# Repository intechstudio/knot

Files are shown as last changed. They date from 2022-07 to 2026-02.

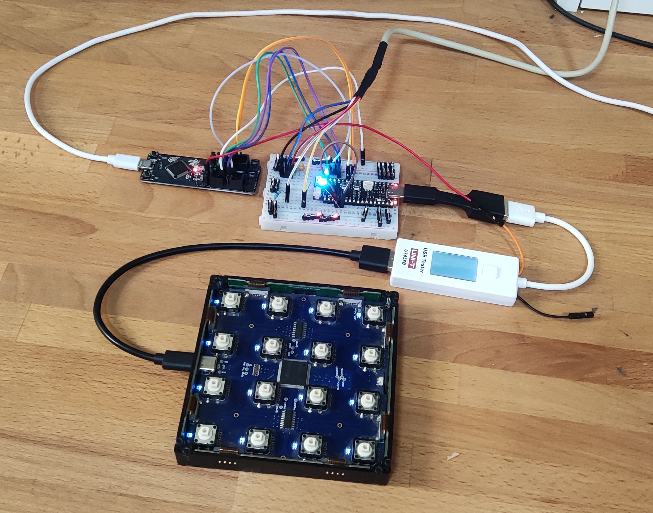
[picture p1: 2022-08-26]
Documentation/prototype.jpg

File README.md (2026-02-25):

## KNOT - USB MIDI Host

Knot is the bridge between old-school MIDI gear like synthesizers, groove boxes, guitar pedals and neat USB MIDI devices. Leave out the computer from the equation and control instruments seamlessly with Grid - or any other - USB controller.

knot, the standalone usb midi host

You can find more info on the [website](https://intech.studio/shop/knot) or in the [Knot - Starter's Guide](https://docs.intech.studio/guides/knot/knot-start).

## Electrical components

| Component | Part number | Preview | Links |
|---|---|---|---|
| KNOT board | PCBA-KNOT |   | [[Schematic]](https://github.com/intechstudio/knot/releases/download/nightly-electrical/PCBA-KNOT_Schematic.pdf) [[STEP]](https://github.com/intechstudio/knot/releases/download/nightly-electrical/PCBA-KNOT-3D.step) [[Gerber]](https://github.com/intechstudio/knot/releases/download/nightly-electrical/PCBA-KNOT-gerber.zip) [[PCB Top]](https://github.com/intechstudio/knot/releases/download/nightly-electrical/PCBA-KNOT_PCB_Top.pdf) [[PCB Bottom]](https://github.com/intechstudio/knot/releases/download/nightly-electrical/PCBA-KNOT_PCB_Bottom.pdf) [[BOM]](https://github.com/intechstudio/knot/releases/download/nightly-electrical/PCBA-KNOT-bom.csv) [[Interactive BOM]](https://github.com/intechstudio/knot/releases/download/nightly-electrical/PCBA-KNOT-ibom.html) |

## Mechanical components

| Component | Part number | Type | Preview | Links |
|---|---|---|---|---|
| Aluminum housing | KNOT-HOUSING | Fabricated |  | [[step]](https://github.com/intechstudio/knot/releases/download/nightly-mechanical/KNOT-HOUSING.step) [[stl]](https://github.com/intechstudio/knot/releases/download/nightly-mechanical/KNOT-HOUSING.stl) [[pdf]](https://github.com/intechstudio/knot/releases/download/nightly-mechanical/KNOT-HOUSING_Drawing.pdf) [[engraving]](https://github.com/intechstudio/knot/releases/download/nightly-mechanical/KNOT-HOUSING_Engraving.pdf) |
| Aluminum front panel | KNOT-FRONT | Fabricated |  | [[step]](https://github.com/intechstudio/knot/releases/download/nightly-mechanical/KNOT-FRONT.step) [[stl]](https://github.com/intechstudio/knot/releases/download/nightly-mechanical/KNOT-FRONT.stl) [[pdf]](https://github.com/intechstudio/knot/releases/download/nightly-mechanical/KNOT-FRONT_Drawing.pdf) |
| Aluminum back panel | KNOT-BACK | Fabricated |  | [[step]](https://github.com/intechstudio/knot/releases/download/nightly-mechanical/KNOT-BACK.step) [[stl]](https://github.com/intechstudio/knot/releases/download/nightly-mechanical/KNOT-BACK.stl) [[pdf]](https://github.com/intechstudio/knot/releases/download/nightly-mechanical/KNOT-BACK_Drawing.pdf) |

### Nightly Firmware version

The nightly firmware is an early release version of the stable release. As it is an early version, some issues could still persist. In the case of issues, please denote the usage of a nightly firmware in the issue report.

[Nightly Release](https://github.com/intechstudio/knot/releases/tag/nightly)

### Updating the firmware

- Hold the mode button while plugging the device using the USB-C port of the Knot.
- The device is identified as a USB mass storage named KNOT-S3 (3 green LEDs).
- The file "INFO_UF2.txt" only contains information for the bootloader version, not the firmware itself.
- You can check the current firmware version, opening the file "CURRENT.UF2" with a text or hexadecimal application.
- The first lines will contain the firmware date text. (e.g "May 29 2024" for the firmware "v1.0.5").
- Download the file "knot_release.zip" from the latest release [Stable Release](https://github.com/intechstudio/knot/releases) and extract it.
- Do not rename the ".uf2" file and copy it to the KNOT-S3 mass storage.
- The device will update and reboot alone.
- 3 blinking white LEDs means that the update is finished and that the device is waiting to a USB MIDI device.

### Knot features

- Standalone USB MIDI Host, works with Grid and any MIDI class compliant USB controller
- TRS MIDI input port
- TRS MIDI output port
- USB-C port for powering, updating the device
- DC in port for powering (6V or 15V with automatic polarity detection)
- Hardware A/B switch for changing the TRS wiring mode
- Mode button for updating the firmware
- 3 indicator LEDs, which will be utilized for various feedback

### USB MIDI Device compatibility with Knot as a host

*If you own a device you couldn't find in the list below, help us out by submitting a test of your own to support@intech.studio!*

| Manufacturer | Device name | Compatibility with Knot | Tester | Note |
| ---- | ---- | ---- | ---- | --- |
| Intech Studio  | Grid | Tested - OK | Intech | |
| Alesis  | Qmini  |  Tested - Not working | Community | |
| AKAI  | MPK Mini MK2  |  Tested - OK | Community | |
| AKAI  | MPK Mini Plus  |  Tested - OK | Community | |
| Arturia  | Beatstep (non-Pro)  |  Tested - OK | Community | |
| Arturia  | Keystep  |  Tested - OK | Community | |
| Arturia  | MiniLab MK2 |  Tested - OK | Community | |
| DoReMIDI  | USB-C MIDI adapter  |  Tested - OK | Community | |
| Elektron  | Digitakt |  Tested - Not working | Community | |
| Korg  | Electribe ES2  |  Tested - OK | Intech | |
| Korg  | Microkey Air 37  |  Tested - OK | Community | |
| Korg  | Nanokey 2  |  Tested - OK | Community | |
| Korg  | Nanopad 2  |  Tested - Not working | Community | |
| Livid Instruments  | DS-1  |  Tested - OK | Community | |
| Midi Fighter  | Midi Fighter Twister  |  Tested - OK | Community | |
| M-AUDIO  | MIDISPORT UNO | Tested - OK | Intech | |
| M-AUDIO | Keystation MK3 (all key sizes) | Tested - Not working | Intech | |
| Novation  | Circuit | Tested - OK | Community | |
| Novation | Launch Control XL2  | Tested - OK | Community | |
| Novation | Launchpad MK3 Mini  | Tested - OK | Intech | |
| Novation  | Launchpad MK2 | Tested - OK | Intech | |
| Novation  | Launchkey 25 | Tested - Only Power | Intech | |
| Roland  | MC-101 | Tested - OK | Community | |
| Sonicware  | ELZ_1  |  Tested - OK | Community | |
| Teenage Engineering  | EP-133 |  Tested - OK | Community | *Knot supplies ample power to the device* |
| Teenage Engineering  | OP-1  |  Tested - No MIDI | Community | |
| Teenage Engineering  | OP-1 field |  Tested - No MIDI | Community | |
| Teenage Engineering  | OP-Z |  Tested - OK | Community | |

### 5-pin DIN/TRS MIDI Device compatibility

*If you own a device you couldn't find in the list below, help us out by submitting a test of your own to support@intech.studio!*

| Manufacturer | Device name | MIDI connector |Compatibility | Tester | Note |
| ---- | ---- | ---- | ---- | ---- | --- |
| 1010music | Blackbox | TRS type-B | Tested - OK |  Community | |
| 1010music | Bluebox | TRS type-B | Tested - OK |  Community | |
| Arturia  | Beatstep (non-Pro) | TS "type-C" |  Tested - !!! | Community | *Needs 3.5mm TS to TRS adapter* |
|Behringer | TD-3-AM | 5-pin DIN | Tested - OK |  Intech | *With adapter* |
|Behringer | U-PHORIA UMC404HD | 5-pin DIN | Tested - OK | Intech | *With adapter* |
| Dreadbox  | Nymphes  | TRS type-B  | Tested - OK | Community | |
| Elektron  | Digitakt | 5-pin DIN | Tested - OK | Community | *With adapter* |
| Korg  | Electribe ES2  | TRS type-B  | Tested - OK | Intech | |
| Korg | Volca Series (Tested on Volca FM)  |  5-pin DIN | Tested - OK | Intech | *With adapter* |
| Mutable Instruments | Yarns | 5-pin DIN | Tested - OK | Intech | *With adapter* |
| Polyend  | Tracker  | TRS type-B | Tested - OK | Intech | |
| Teenage Engineering  | EP-133 | TRS type-A | Tested - OK | Community |  |
| Teenage Engineering  | OP-Z | TRS type-A | Tested - OK | Community | *With Line Module* |
| Woovebox  | Woovebox | TRS type-A | Tested - OK | Community | |

<!---
### Community contributors

A big thank you to our community contributors for testing these devices:
- Michal
- Tibi

|    Dirtywave  | M8 Tracker  | TRS type-A | Untested | - |
|   Audiothingies   | Micromonsta 2  | TRS type-A | Untested | - |
|    Bastl Instruments  | Softpop SP2  | 5-pin DIN | Untested | - |
|    Elektron  | Octatrack  | 5-pin DIN | Untested | - |
|    Elektron  | Syntax  | 5-pin DIN | Untested | - |
|    Elektron  | Digitakt  | 5-pin DIN | Untested | - |
|    Elektron  | Digitone  | 5-pin DIN | Untested | - |
|    Elektron  | Analog Rytm  | 5-pin DIN | Untested | - |
|    Elektron  | Analog Four  | 5-pin DIN | Untested | - |
|    Elektron  | Analog Keys  | 5-pin DIN | Untested | - |
|    Elektron  | Model:Samples  | TRS type-A | Untested | - |
|    Elektron  | Model:Cycles  | TRS type-A | Untested | - |
|    Arturia  | Microfreak  | TRS type-A  | Untested | - |
--->

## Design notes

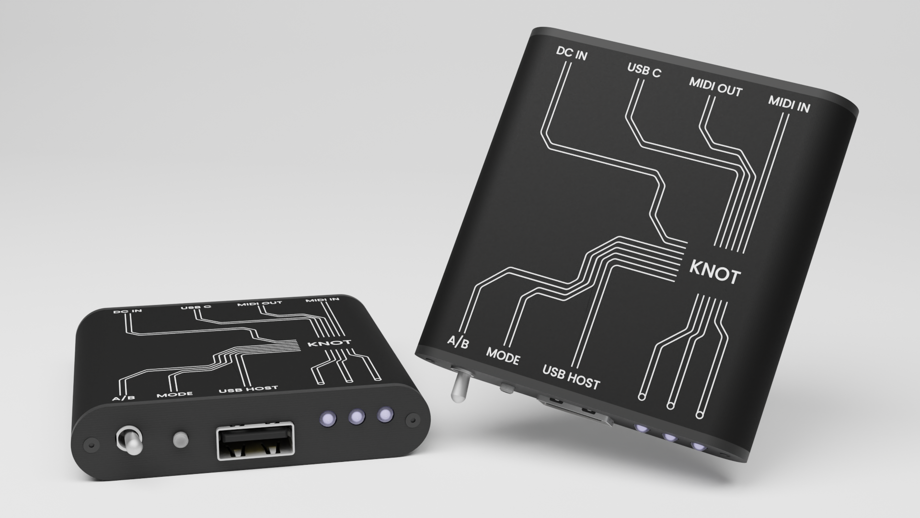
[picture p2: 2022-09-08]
Documentation/knot.png

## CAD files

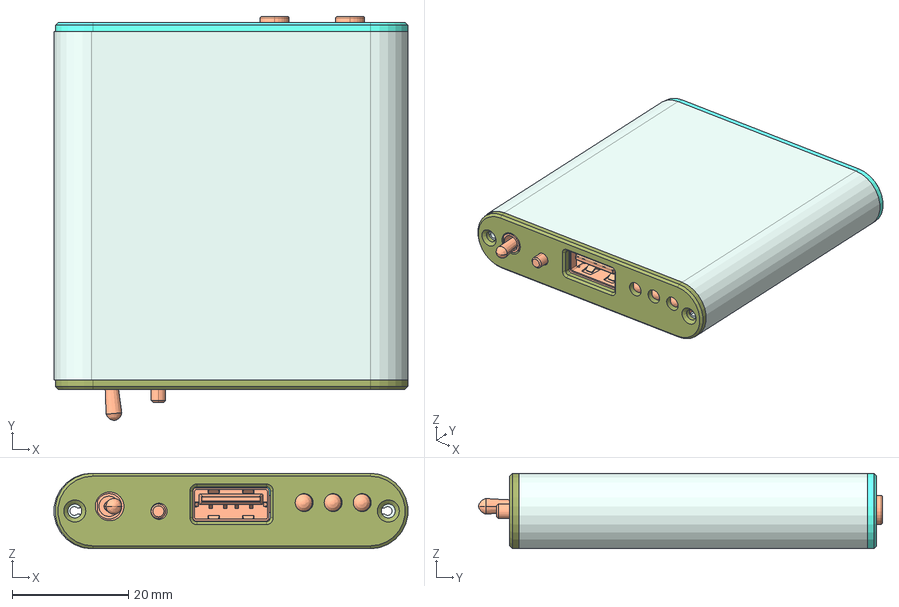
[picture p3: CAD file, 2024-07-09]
Mechanical/Design/KNOT-ASSEMBLY/KNOT-ASSEMBLY.FCStd
60.9 x 69.6 x 13.0 mm
KNOT-PCB_001
KNOT-HOUSING_001
KNOT-FRONT_001
KNOT-BACK_001

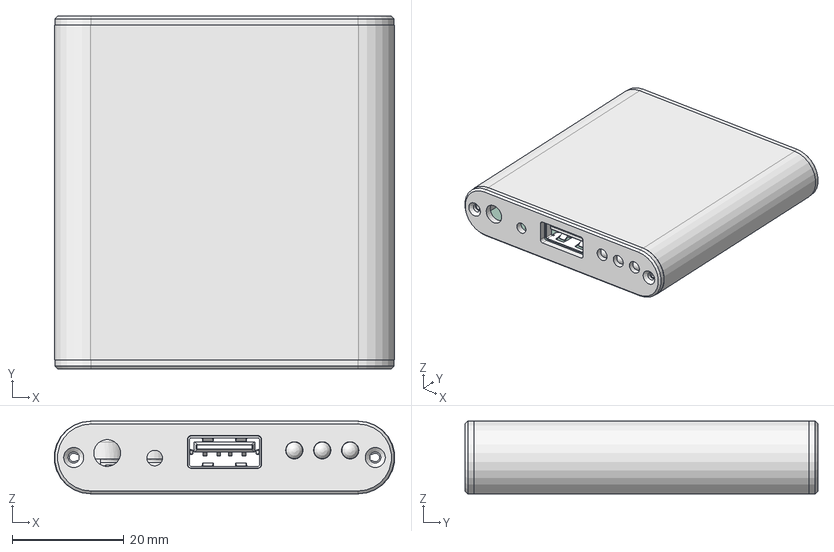
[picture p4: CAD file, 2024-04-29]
Mechanical/MIDI_Host_assembly.FCStd
60.9 x 63.2 x 13.0 mm
Alu
Front
Back
PCBA-KNOT PCB

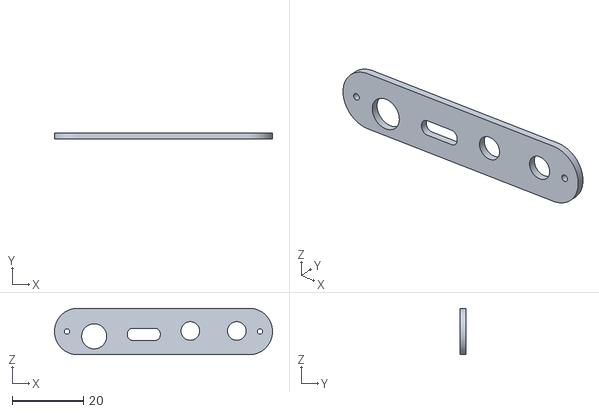
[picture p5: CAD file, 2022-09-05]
Render/render/MIDI_Host_assembly-Back.stl
61.0 x 1.60 x 13.0

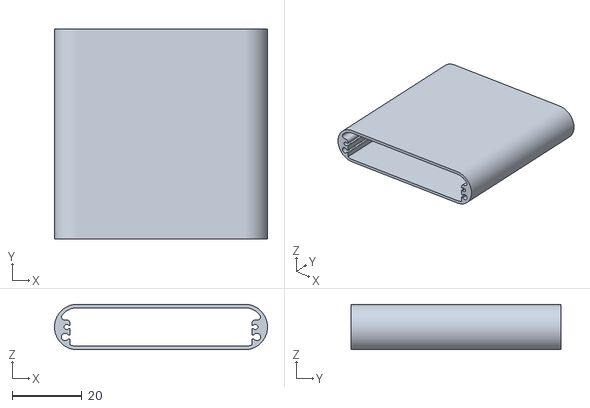
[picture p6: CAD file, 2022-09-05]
Render/render/MIDI_Host_assembly-Alu.stl
61.0 x 60.0 x 13.0

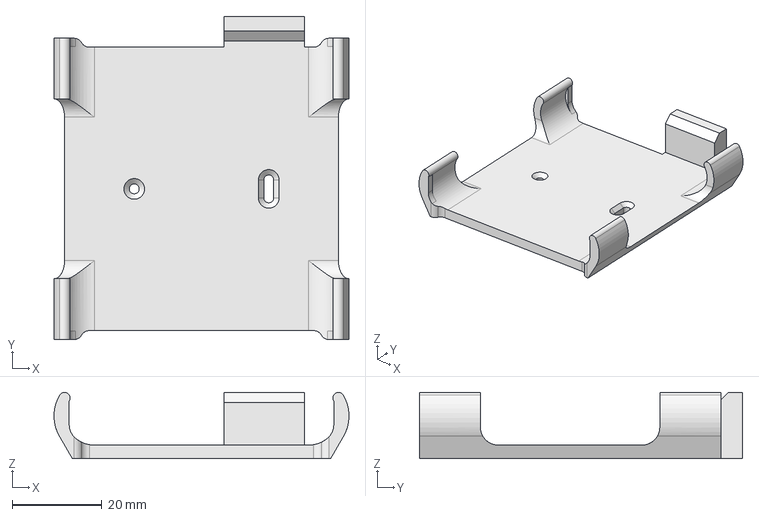
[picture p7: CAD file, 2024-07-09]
Mechanical/Design/KNOT-HOLDER/KNOT-HOLDER.FCStd
65.8 x 72.1 x 14.7 mm

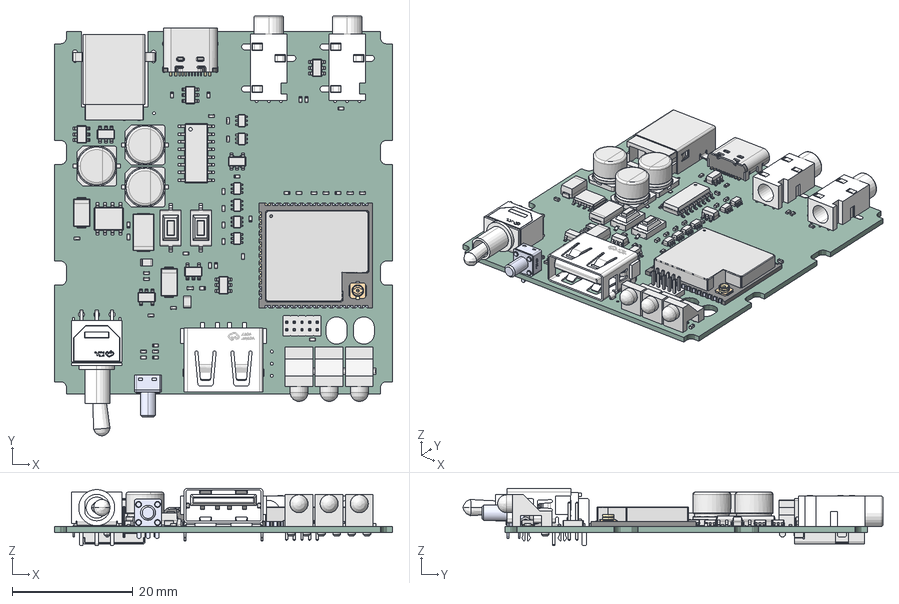
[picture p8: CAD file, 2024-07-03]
Mechanical/Design/KNOT-PCB/KNOT-PCB.FCStd
56.0 x 69.6 x 9.50 mm
R_0402_1005Metric063
SOT_363_SC_70_012
C_0402_1005Metric066
C_0402_1005Metric068
R_0402_1005Metric065
D_SMA006
LEG012
LEG013
LEG014
LEG015
ESP32-S3-WROOM-1U057
ESP32-S3-WROOM-1U058
ESP32-S3-WROOM-1U059
ESP32-S3-WROOM-1U060
ESP32-S3-WROOM-1U061
ESP32-S3-WROOM-1U062
ESP32-S3-WROOM-1U063
ESP32-S3-WROOM-1U064
ESP32-S3-WROOM-1U065
ESP32-S3-WROOM-1U066
ESP32-S3-WROOM-1U067
ESP32-S3-WROOM-1U068
ESP32-S3-WROOM-1U069
ESP32-S3-WROOM-1U070
ESP32-S3-WROOM-1U071
ESP32-S3-WROOM-1U072
ESP32-S3-WROOM-1U073
ESP32-S3-WROOM-1U074
ESP32-S3-WROOM-1U075
ESP32-S3-WROOM-1U076
ESP32-S3-WROOM-1U077
ESP32-S3-WROOM-1U078
ESP32-S3-WROOM-1U079
ESP32-S3-WROOM-1U080
ESP32-S3-WROOM-1U081
ESP32-S3-WROOM-1U082
ESP32-S3-WROOM-1U083
ESP32-S3-WROOM-1U084
ESP32-S3-WROOM-1U085
ESP32-S3-WROOM-1U086
ESP32-S3-WROOM-1U087
ESP32-S3-WROOM-1U088
ESP32-S3-WROOM-1U089
ESP32-S3-WROOM-1U090
ESP32-S3-WROOM-1U091
ESP32-S3-WROOM-1U092
ESP32-S3-WROOM-1U093
ESP32-S3-WROOM-1U094
ESP32-S3-WROOM-1U095
ESP32-S3-WROOM-1U096
ESP32-S3-WROOM-1U097
ESP32-S3-WROOM-1U098
ESP32-S3-WROOM-1U099
ESP32-S3-WROOM-1U100
ESP32-S3-WROOM-1U101
ESP32-S3-WROOM-1U102
ESP32-S3-WROOM-1U103
ESP32-S3-WROOM-1U104
ESP32-S3-WROOM-1U105
ESP32-S3-WROOM-1U106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

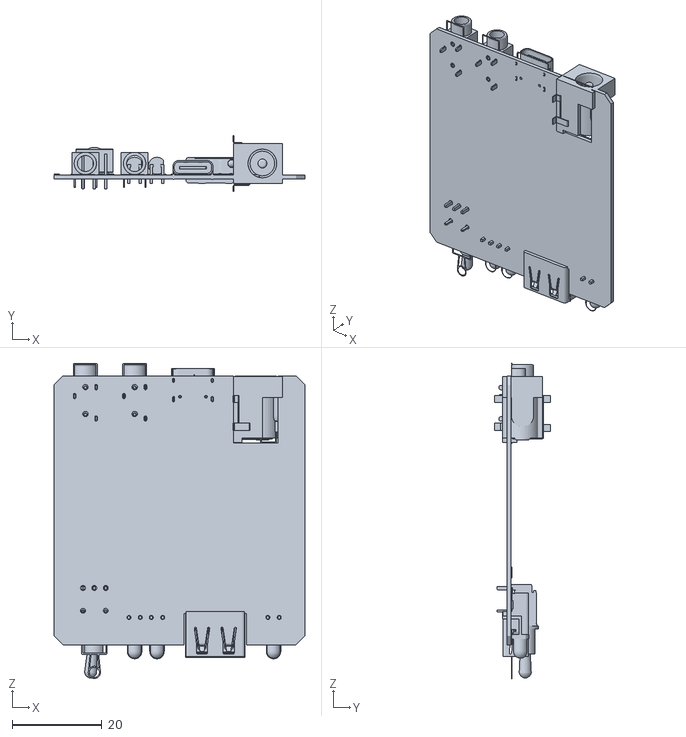
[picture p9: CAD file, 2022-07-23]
Render/untitled.stl
56.0 x 12.5 x 70.3

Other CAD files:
Render/render/MIDI_Host_assembly-Front.stl
Mechanical/Design/KNOT-BACK/KNOT-BACK.FCStd
Mechanical/Design/KNOT-FRONT/KNOT-FRONT.FCStd
Mechanical/Design/KNOT-HOUSING/KNOT-HOUSING.FCStd
Mechanical/Design/KNOT_mfg/KNOT-BACK.step
Mechanical/Design/KNOT_mfg/KNOT-FRONT.step
Mechanical/Design/KNOT_mfg/KNOT-HOUSING.step
Mechanical/Design/archive/mfg/MIDI_Host_assembly-Front2.step
Mechanical/Design/archive/mfg/MIDI_Host_assembly-Front.step
Mechanical/Design/archive/mfg/MIDI_Host_assembly-Alu.step
Mechanical/Design/archive/mfg/MIDI_Host_assembly-Back.step

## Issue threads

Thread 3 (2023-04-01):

Possible to make USB HOST driver "pluggable"?

marchingband, 2023-04-01:
When I unplug a USB device, the application crashes.
```
E (10592) USBH: Device 1 gone
ESP_ERROR_CHECK failed: esp_err_t 0x103 (ESP_ERR_INVALID_STATE) at 0x40378f54
```

PS. I am fan-boy-ing out over here, all your products are fantastic <3

marchingband, 2023-04-01:
I see in the example code:
```
        if (driver_obj.actions == 0) {
            usb_host_client_handle_events(driver_obj.client_hdl, portMAX_DELAY);
        } else {
            ... we handle events
        }
```

but in yours:
```
        usb_host_client_handle_events(driver_obj.client_hdl, 10);
        ... we handle events
```
Perhaps this leaves the driver in an invalid state such that it cannot be deregistered / uninstalled?

marchingband, 2023-04-01:
running the example code from esp-idf, when I unplug a device I get:
```
E (259720) USBH: Device 1 gone
I (259720) CLASS: Deregistering Client
I (259720) DAEMON: No more clients and devices
```
So the daemon task is seeing that the client is gone and can close well, which does not happen in yours, this 3rd log never occurs.

marchingband, 2023-04-01:
I see you replaced `driver_obj->actions &= ~ACTION_GET_STR_DESC;` in the get_string_descriptor with a loop counter.
I wonder if you could help me understand why this is setup the way it is. I would love to help get this running as a pluggable driver.

marchingband, 2023-04-01:
Ok I have fixed it but there are some major changes, l'll outline them here, just let me know if you'd like a PR, or if you want to discuss, or if you don't care that's totally understandable too, I realize that your device works perfectly just crashing and starting from the beginning.
I will leave some code here to help anyone else who may end up here.

`aciton_close_dev()` deletes some info that is needed to close the host, so I don't call that, instead, when the callback receives `ACTION_CLOSE_DEV`, just break
```
            if (driver_obj.actions & ACTION_CLOSE_DEV) {
                // aciton_close_dev(&driver_obj);
                break;
            }
```
 and then here is the closing code which I add at the end of `class_driver_task()`
```
    // Cancel polling of BULK IN and OUT endpoints
    transfer->callback = NULL;
    in_transfer->callback = NULL;

    // Reset the endpoints
    ESP_ERROR_CHECK(usb_host_endpoint_halt(driver_obj.dev_hdl, transfer->bEndpointAddress));
    ESP_ERROR_CHECK(usb_host_endpoint_flush(driver_obj.dev_hdl, transfer->bEndpointAddress));

    ESP_ERROR_CHECK(usb_host_endpoint_halt(driver_obj.dev_hdl, in_transfer->bEndpointAddress));
    ESP_ERROR_CHECK(usb_host_endpoint_flush(driver_obj.dev_hdl, in_transfer->bEndpointAddress));

    ESP_LOGI(TAG, "Free transfers");
    ESP_ERROR_CHECK(usb_host_transfer_free(transfer));

    ESP_LOGI(TAG, "Free in_transfers");
    ESP_ERROR_CHECK(usb_host_transfer_free(in_transfer));

    // Release the host
    ESP_ERROR_CHECK(usb_host_interface_release(driver_obj.client_hdl, driver_obj.dev_hdl, interface_num ));

    // Close the device
    ESP_ERROR_CHECK(usb_host_device_close(driver_obj.client_hdl, driver_obj.dev_hdl));

    ESP_LOGI(TAG, "Deregistering Client");
    ESP_ERROR_CHECK(usb_host_client_deregister(driver_obj.client_hdl));

    //Wait to be deleted
    ESP_LOGI(TAG, "Giving semaphore");
    xSemaphoreGive(signaling_sem);

    ESP_LOGI(TAG, "Suspending self");
    vTaskSuspend(NULL);
```
The only special value in here is `interface_num` which I declare globally
```
uint8_t interface_num = 0;
```
And inside `action_get_config_desc()` I added one line
```
    ESP_LOGI(TAG, "SUKU claim interface %d nice", intf_num);
    ESP_ERROR_CHECK(usb_host_interface_claim(driver_obj->client_hdl, driver_obj->dev_hdl, intf_num, 0));

    // save the intf_num for deregistration
    interface_num = intf_num;

    usb_host_transfer_alloc(4, 0, &transfer);
```
This code closes the host driver, after which we can run everything from scratch, and wait for a new device.
How to best handle this plug/unplug cycle is up for debate, but I have a task that manages the plugging. It starts the tasks, waits on the semaphore, and then deletes the tasks, in a loop.

```
static void usb_h_task(void *arg)
{
    while(1)
    {
        ESP_LOGI(TAG, "creating usb host driver tasks");
        SemaphoreHandle_t signaling_sem = xSemaphoreCreateBinary();

        TaskHandle_t daemon_task_hdl;
        TaskHandle_t class_driver_task_hdl;

        //Create daemon task
        xTaskCreatePinnedToCore(host_lib_daemon_task,
                                "usb_h_daemon",
                                4096,
                                (void *)signaling_sem,
                                DAEMON_TASK_PRIORITY,
                                &daemon_task_hdl,
                                0);

        //Create the class driver task
        xTaskCreatePinnedToCore(class_driver_task,
                                "usb_h_class",
                                4096,
                                (void *)signaling_sem,
                                CLASS_TASK_PRIORITY,
                                &class_driver_task_hdl,
                                0);

        vTaskDelay(10);     //Add a short delay to let the tasks run

        //Wait for the tasks to complete
        xSemaphoreTake(signaling_sem, portMAX_DELAY);

        ESP_LOGI(TAG, "deleteting usb host tasks");
        //Delete the tasks
        vTaskDelete(class_driver_task_hdl);
        vTaskDelete(daemon_task_hdl);
    }

}
```
I imagine there are some memory leaks in here, and maybe some unnecessary steps or easier ways to do things, but, I plugged and unplugged like a crazy person and it seems to work well.
Ok over and out <3

marchingband, 2023-04-01:
The end product:
https://github.com/ultrapalace/mainframe/blob/main/main/usb_h.c
https://github.com/ultrapalace/mainframe/blob/main/main/usb_h_class.c

Closed 2023-04-01.

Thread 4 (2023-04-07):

I can connect to upload the firmware, but how?

giacecco, 2023-04-07:
The page at https://intech.studio/shop/knot describes how to connect with the Knot to upgrade the firmware, but doesn't say what to do next!

I can see that there is a `CURRENT.UF2` file in the Knot, while the latest release at https://github.com/intechstudio/knot/releases includes a `knot_release_2023-02-08-1025.uf2` file. Shall I overwrite the old one? Shall I just upload the new one without renaming? I don't want to risk bricking it.

In the Knot I also see an `INFO_UF2.TXT` file saying:

```
TinyUF2 Bootloader ca0cacd - tinyusb (0.12.0-203-ga4cfd1c69)
Model: Intech Studio Knot
Board-ID: ESP32S3-Knot
Date: Sep  7 2022
```

... so it looks like a firmware update is due!

Closed 2023-07-20.

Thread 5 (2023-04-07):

Voltage for DC-in?

giacecco, 2023-04-07:
At the back of the Knot, it says `6-15V DC`. It looks like it could take anything _between_ 6 and 15, but in reality, it wants exactly 6 or 15. I tried with a 9V I use with my pedal and the Knot did not turn on. Please change the label to `6V or 15V DC`.

I have made a pull requests to update the website accordingly, too.

SukuWc, 2023-07-20:
What polarity is the 9V power supply? Early on knot units the automatic polarity detection was not working correctly, so if the power supply is center negative variant (typically used by guitar pedals) then that could be the problem!

Closed 2024-01-09.

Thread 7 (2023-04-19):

MIDI received on TRS IN causes power cycle on Knot when hosting some devices

narayb, 2023-04-19:
Reproduced on Novation Launchpad MK3 Mini.
No effect when hosting Grid.

SukuWc, 2023-07-20:
Can we confirm that this is still a problem using v1.0.2 firmware on knot

Closed 2024-01-09.

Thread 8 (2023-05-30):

FW Update = Pulsing white LED's

lucasfackler, 2023-05-30:
After dropping the latest release .UF2 onto the disk, Knot reboots and now LED's are white and pulse slowly.
What does this mean? No MIDI either.

SukuWc, 2023-07-20:
That means that knot is waiting for a MIDI controller to be connected! What midi controller are you trying to connect?

narayb, 2023-07-20:
We have solved this issue a while back, you can close it if that's alright with you.

Closed 2024-01-09.

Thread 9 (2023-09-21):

Feature request: let Knot remember the Mode setting

narayb, 2023-09-21:
In certain workflows users would use the Blue Mode with MIDI Through/Merge exclusively, but at the moment this requires setting the Mode after each power cycle.

It would be preferable if Knot could remember the last Mode set until the next boot.

mulkeybe, 2023-11-09:
This would be a very useful feature. I run an external Midi clock into my knot and merge it with Grid controller MIDI data stream. It would be nice if knot would remember the mode so I wouldn’t have to press the utility button every time that I power up my system

narayb, 2023-11-09:
This is a work in progress feature, more news soon!

kkerti, 2024-01-13:
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
Please let me (or users on the discord community channel) know if we have an ETA for this.

SukuWc, 2024-03-18:
Feature implemented, fix coming soon in firmware version v1.0.3

Closed 2024-03-18.

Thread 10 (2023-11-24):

Add instructions for updating firmware

jmickelin, 2023-11-24:
There doesn't seem to be any clear instructions for updating the firmware, either here on Github or on the retail page. The latter has a link called "Firmware update" on https://docs.intech.studio/, but it takes you to a page describing firmware updates only for the Grid controllers.

One _could_ deduce that updating works similarly on the Knot as the instructions under the "Updating the firmware manually" section on the Grid page (holding the mode button while connecting the USB-C port to a computer makes the Knot present itself as a USB mass storage device, to which you copy the `.uf2` file, and then unmount the device to perform the installation). This is not at all obvious, however, especially since the Grid page starts by describing a different update method which does not seem at all applicable to the Knot, so most users would click away from the page right away. The only hint about firmware updates being possible at all is a single sentence in the bullet point list of the Knot's features (`"• Mode button for updating the firmware"`), and the fact that there are Releases of `.uf2` files on the Github repo.

Much clearer would be to have a dedicated page for the Knot's firmware update instruction as well, even if the steps described end up being identical as for the Grid.

The Grid firmware update page also contains warnings about making sure to select the firmware corresponding to the correct microcontroller by reading the `INFO_UF2.TXT` file on the mass storage device and choosing the correct binary. This does not seem to be applicable to the Knot, since the firmware release only has one flavour of binary (corresponding to the ESP32) and would probably not need to be present on the Knot firmware update page. However, for the sake of clarity and consistency, the filename for the firmware should be renamed to make it explicit that it is for the ESP32 board, using the same naming scheme as the Grid's firmware releases. For instance: `knot_esp32_release_2023-07-18-1139.uf2`. This removes one extra layer of doubt for users and serves as a slight sanity check before the "here-goes-nothing" moment when doing the update.

SukuWc, 2024-01-09:
Thanks for the feedback I fixed the naming of the .uf2 file. I will also forward this issue to website and documentation teams! @narayb

Closed 2024-01-09.

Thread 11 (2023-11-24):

Display the version number of the current firmware in INFO_UF2.TXT

jmickelin, 2023-11-24:
The contents of the `INFO_UF2.TXT` file that shows up when the device is mounted for firmware updating currently looks something like this

```
TinyUF2 Bootloader ca0cacd - tinyusb (0.12.0-203-ga4cfd1c69)
Model: Intech Studio Knot
Board-ID: ESP32S3-Knot
Date: Sep  7 2022
```

It can be a bit unclear that the version number, date and ref hash correspond to the version of the bootloader and not that of the firmware itself. After updating my firmware (using mostly guesswork since there aren't any instructions as of me writing this), I thought I could confirm whether the update had worked by seeing if the contents of the `INFO_UF2.TXT` had updated, and had to do a double take when I discovered they hadn't.

Adding a second set of lines describing the firmware version would therefore help.

(What I ended up doing was to copy the `CURRENT.UF2` file to my system and reading the top of the file in a hex editor, to reveal the version information:

```
$ xxd CURRENT.UF2
[...]
00000090: 3131 3a33 383a 3131 0000 0000 0000 0000  11:38:11........
000000a0: 4a75 6c20 3138 2032 3032 3300 0000 0000  Jul 18 2023.....
000000b0: 7635 2e32 2d64 6576 2d31 3733 362d 6761  v5.2-dev-1736-ga
000000c0: 3264 3736 6164 3338 6100 0000 0000 0000  2d76ad38a......
[...]
```

It works, but it's not very ergonomic.)

jmickelin, 2023-11-24:
I see now that the bootloader info is created by TinyUF2 and not trivially extendable with more information, at least not information that can be changed when just flashing new firmware and leaving the bootloader untouched. After some investigation, this is also the case for the contents of the `INDEX.HTM` file...

I will close this as WONTFIX, unless you disagree :)

Closed 2023-11-24.

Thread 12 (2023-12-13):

USB host options

copych, 2023-12-13:
Hello, guys! Very nice and promising product! Please, tell me if it's possible to use USB host port with an USB hub, or am I asking too much? =)

SukuWc, 2024-01-09:
I just checked and the tinyusb library does support hub in host mode, so it is possible that we can implement this in the Knot firmware.

brendamnfine, 2024-01-17:
This would make this unit so powerful! I would very much like to be able to connect a USB hub to use more than one midi controller in my set up.

SukuWc, 2025-02-23:
Hi @brendamnfine,  Good news!

ESP IDF 5.4 was just released, and now there is USB HUB support built in. We will check it out in the coming weeks!
#21

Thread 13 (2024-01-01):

Feature request: make a better use of Knot's USB C port

giacecco, 2024-01-01:
You describe on the Knot web page that the USB C port can be used for firmware updates. That suggests it is a "smart" port, not just for power.

Then, why not make the Knot's USB C port act as a "proxy" of the USB C port of the Grid module it is connected to? There's lots of advantages in doing that:

1. MIDI Out messages would go to both TRS and USB, and
2. we can use the Grid Editor when the Knot is connected

That would be amazing and would simplify connectivity a lot, when using both USB and TRS/DIN devices. Thanks.

SukuWc, 2024-01-09:
The ESP32-S3 microcontroller has only one USB peripheral. We use multiplexers to switch between having the data pins connected to the USB-C port and the USB-A port.

The inactive port (not connected to native USB pins) is connected to a free pair of GPIO pins, so there is a possibility of using a bit-banged USB library but that would most likely only support USB low speed...

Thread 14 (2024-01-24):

Knot doesn't forward all messages, resulting in hanging notes, jittery clock

narayb, 2024-01-24:
Reported originally by user named neon on our Discord. Ticket created after reproducing bug in a similar setup. Tested with release FW.

[Video](https://www.youtube.com/shorts/p3hEpaD7vbk)

## Setup used

The setup consists of a MIDI keyboard sending notes into the IN port of Knot and Knot forwarding that into the HOST port. In this case a synth is hosted in the port, Knot is powering it.

Original setup was tested with multiple MIDI keyboards and synths. Reproduced with Atruria Keystep + Audiothingies Micromonsta 2 (see video).

## Steps to reproduce

After creating the setup, pressing more than two keys at the same time and releasing them simultaneously would result in hanging notes 30% of the time.

After testing more, the issue could also be reproduced with just one note + pressure from the Keystep in 80% of tries.

## Conclusions

When multiple messages are received at the IN port, Knot sometimes struggles to process these and misses some in the process. The messages *are* properly sent each time from the Keystep as illustrated by the monome norns on the side, showing us a MIDI monitor on the video footage.

narayb, 2024-02-05:
Bug confirmed still active on current nightly FW. When doing so, MIDI monitor shows no NOTE OFF messages received.

narayb, 2024-03-06:
A user added his own experience about lag with Knot on the [forums](https://forum.intech.studio/t/experiencing-some-lag-with-knot/94) and we received user reports of this issue on Support as well, using a MIDI Fighter Twister for sending note on messages.

narayb, 2024-04-10:
Firmware update v1.0.2 mitigated the issue and one use-case is reportedly stuck-note-free. There still are use-cases that experience the issue however.

- Some USB devices when hosted in the USB HOST port can create stuck notes when controlling a MIDI instrument through the MIDI OUT port e.g. MIDI Fighter 64. Bug not present on Grid.
- Some users experienced jitter/MIDI delay when passing clock through Knot. Investigating.
- A user reported a strange message sent by Knot on a bootup through the MIDI OUT port, hosted device or not. Investigating.

jmickelin, 2024-05-05:
I have been experiencing the problem in the first bullet point as well. Sadly, updating to the latest firmware (v1.0.4) does not help.

The hardware I have tested it with are the following:
* Controllers (connected via USB to the USB HOST port):
  - My own Korg MicroKey Air (S/N: MICROKEY2-37AIR), confirmed to be using the latest firmware.
  - A different mini MIDI keyboard, which I believe was an Akai LPK25, though I am not 100% sure.
* Instruments (connected via TRS to the MIDI OUT port):
  - A Dreadbox Nymphes synth, confirmed to be using the latest firmware.
  - A computer running a simple MIDI application to visualize the keys being pressed (`vmpk`). Connected using a ESI MidiMate eX USB-MIDI interface between the Knot's MIDI OUT and the computer's USB.

All combinations of setups exhibited the problem with stuck notes as soon as the signal was running through Knot. Connecting the MIDI keyboards directly via USB to the computer worked without issue. Sadly I do not own any non-USB controllers to similarly test the Nymphes directly without the Knot.

---

I have been meaning to file a bug report for this for a long time, but never got around to it. So I'm happy to see that others have done so! Hopefully I can at least provide an additional data point to help figure out the issue.

SukuWc, 2025-01-29:
Jitter issue fixed, now merged to stable branch

jmickelin, 2025-01-30:
I'm still getting stuck notes on the latest Nightly firmware (`2025-01-29-1113`), with the same setup as above. It occurs whenever I press and release a handful of keys at the same time. At least one of them is likely to be stuck until I hit the same key again.

narayb, 2025-01-30:
No, your update has worked perfectly. The patch only addressed the clock jitter issue and has done nothing to the stuck notes. This is an unfortunate case of two issues in one, I will open a new issue for stuck notes exclusively.

jmickelin, 2025-01-31:
Ah, I see! Thank you :)

Closed 2025-01-29.

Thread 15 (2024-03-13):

Knot currently does not support sending or receiving MIDI messages using Running Status

narayb, 2024-03-13:
What is running status: http://midi.teragonaudio.com/tech/midispec/run.htm

Currently if running status is received on the MIDI IN or MIDI OUT ports, the message gets ignored by Knot.

hikari-no-yume, 2025-09-16:
@benblaise-intech Since you closed it, can you rename this issue to “Knot does not currently support _receiving_ MIDI messages using Running Status”? It still lacks support for sending them, but that's a different and less important thing, more of a performance/latency optimisation, and could be its own issue if it really needs tracking.

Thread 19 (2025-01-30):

Sending Knot note on messages results in stuck notes

narayb, 2025-01-30:
[Referring back to this earlier issue](https://github.com/intechstudio/knot/issues/14).

Issue reproduced on both Grid and other hosted devices. Fix pending.

hikari-no-yume, 2025-09-10:
This may not be the entire issue, but part of this is the lack of Running Status support (https://github.com/intechstudio/knot/issues/15), as far as I could tell in my testing anyway (https://github.com/intechstudio/knot/pull/28).

hikari-no-yume, 2025-09-10:
I'm not sure if this issue is about Note Ons received over USB or over TRS. But in the case of TRS/DIN MIDI: a _lot_ of stuck note issues are caused by a lack of Running Status support (https://github.com/intechstudio/knot/issues/15), which I have a fix for in a PR (https://github.com/intechstudio/knot/pull/28). The reason the lack of Running Status support causes stuck notes is that, very often, a sequence of Note Ons **and Note Offs** is sent as a single Status byte for the Note On, then a long series of Data bytes with no repeated Status byte (i.e. Running Status is used). There isn't even necessarily a new Status byte for the Note Off, because that can be sent as a Note On with velocity = 0. All four of the MIDI controllers with DIN output that I've tested had serious stuck note issues with the KNOT before applying my Running Status patch, and all four of them appear to work flawlessly now. However: three out of four of those controllers are Yamaha products, and for all I know, the KNOT might have some other issues that also can cause stuck notes sometimes, so I can't say for sure that this *completely* fixes stuck note problems.

hikari-no-yume, 2025-09-10:
One of my devices is the "Squier Stratocaster Guitar and Controller", which exhibited the absolute worst case for the stuck note problems: the keyboard I was trying to connect it to via the KNOT produced, seemingly, _no sound whatsoever_.

The following is **pure speculation**, but I think that might be because it's a guitar controller, and every new note you play on a string cancels the previous note. So it was probably sending something like

> [Status: Note On, channel 1], [Data: note E4], [Data: velocity 0], [Data: note F#4], [Data: velocity 100]

every time a string was played, and the KNOT would only see the "[Status: Note On, channel 1], [Data: note E4], [Data: velocity 0]" bit, which is effectively a Note Off. The interesting part, "[Data: note F#4], [Data: velocity 100]", would have been missed because of the lack of Running Status. So perhaps only Note Off messages made their way to the keyboard, and that's why I heard no sound? I hope that's illustrative.

jmickelin, 2025-09-10:
I think the issue addresses both. At least the setups I've tested and reported on in the previous issue had controllers plugged into the USB host side of the Knot. But maybe there are two separate issues at play here, causing the same symptoms: One on the USB side and one on the TRS one.

I did compile your branch and try it out, just in case. It didn't fix my USB-MIDI controller issues, but I guess that was to be expected 😄

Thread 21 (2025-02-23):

Resources: USB host reliability and features

SukuWc, 2025-02-23:
## USB HUB Support
https://github.com/espressif/esp-idf/releases/tag/v5.4

## Bulk transfer reliability
https://github.com/touchgadget/esp32-usb-host-demos/tree/main/examples/usbhmidi
https://www.esp32.com/viewtopic.php?f=2&t=31554&p=108456#p108456
https://github.com/espressif/esp-idf/issues/10571

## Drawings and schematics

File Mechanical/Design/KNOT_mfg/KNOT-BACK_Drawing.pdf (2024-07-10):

B

2× ⌀5,2 ± 0,05

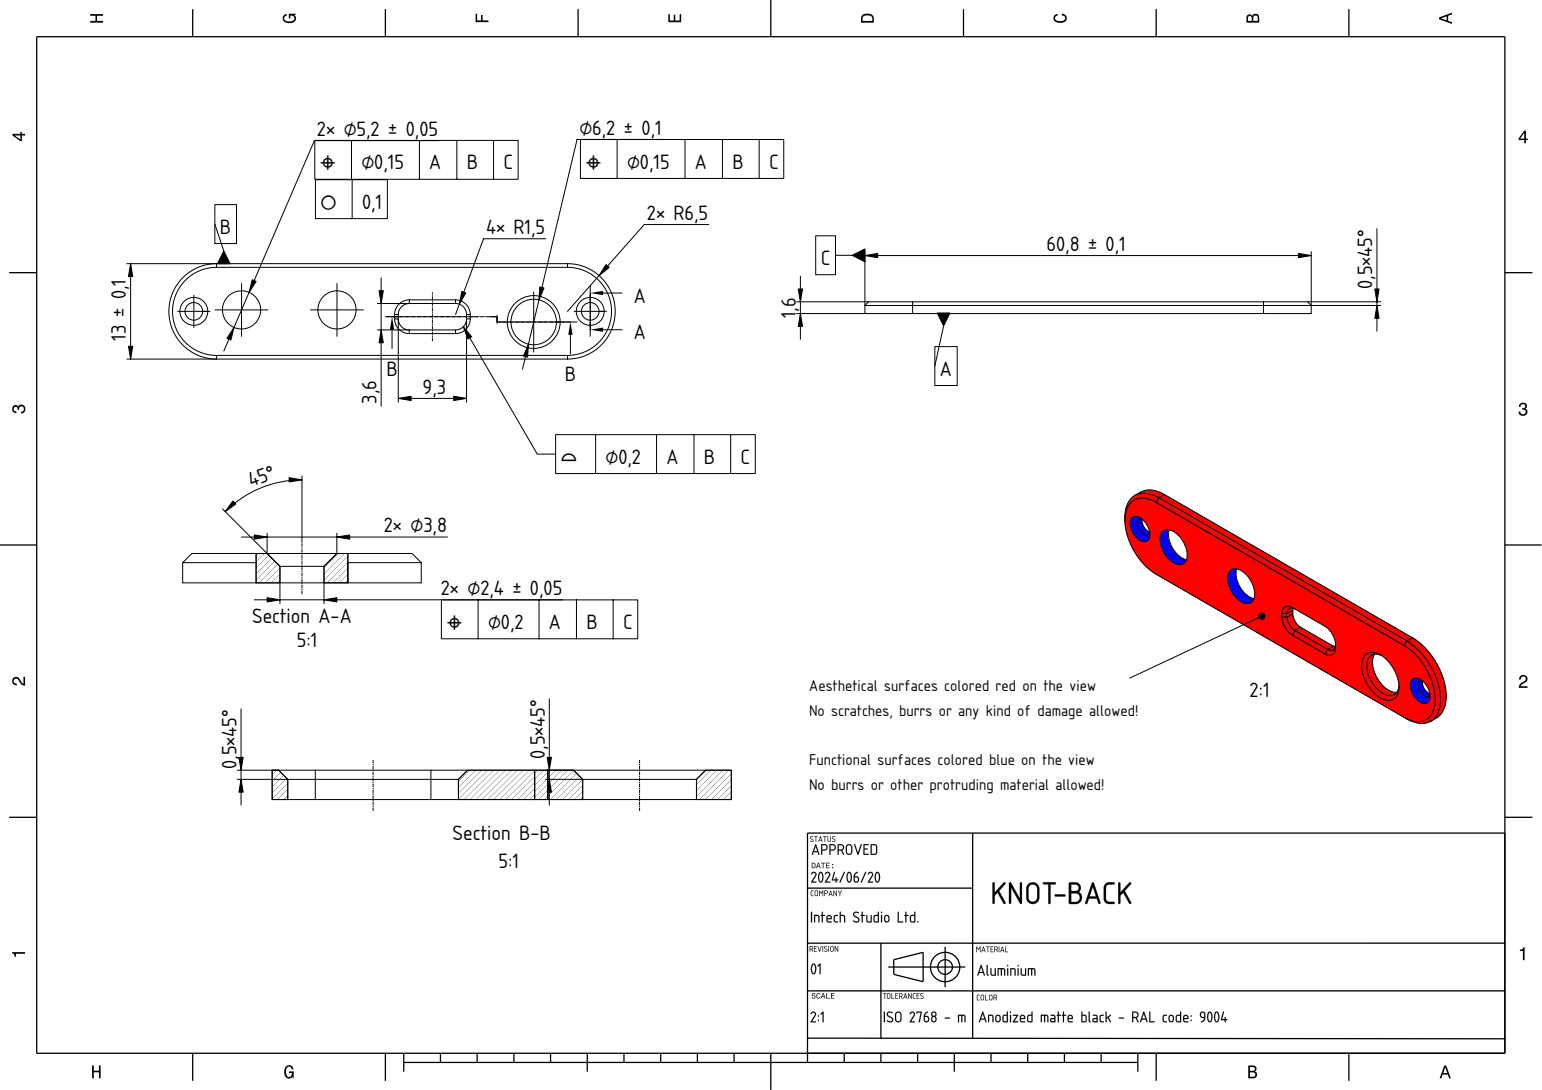
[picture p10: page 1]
Section A-A; Section B-B

Aesthetical surfaces colored red on the view

No scratches, burrs or any kind of damage allowed!

Functional surfaces colored blue on the view

No burrs or other protruding material allowed!

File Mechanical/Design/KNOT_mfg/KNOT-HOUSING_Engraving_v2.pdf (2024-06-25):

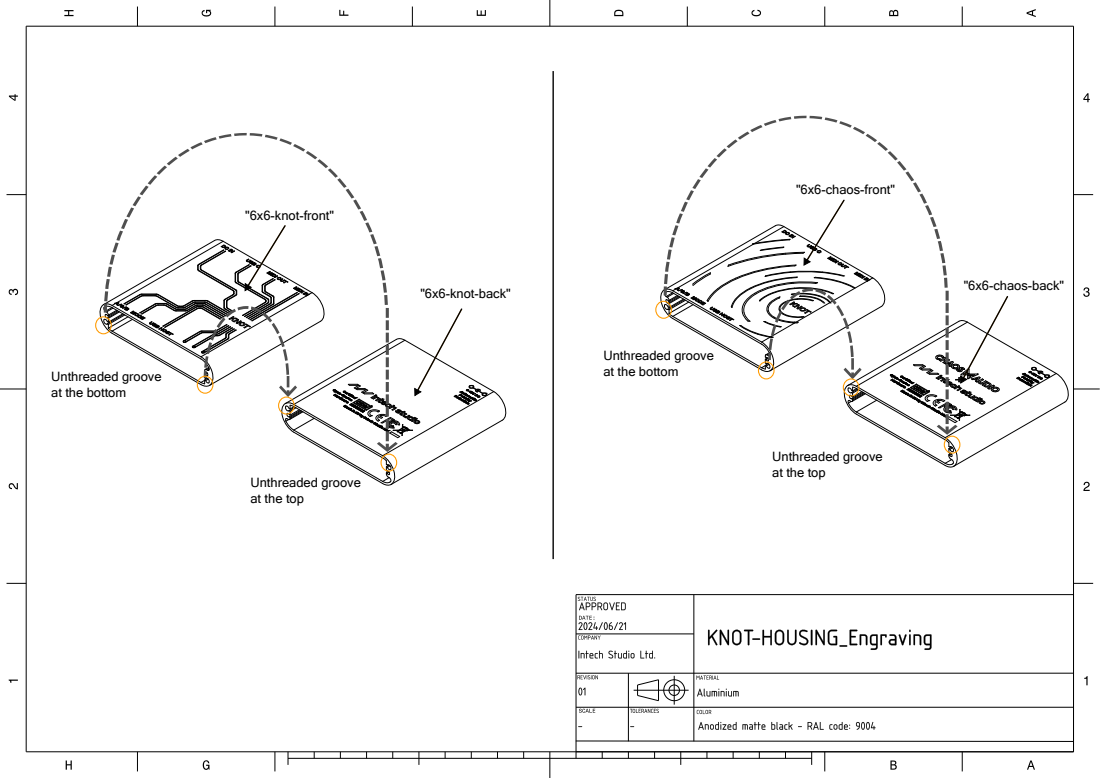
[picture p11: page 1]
"6x6-knot-front"; "6x6-chaos-front"; "6x6-knot-back"; "6x6-chaos-back"

Unthreaded groove
at the bottom

at the top

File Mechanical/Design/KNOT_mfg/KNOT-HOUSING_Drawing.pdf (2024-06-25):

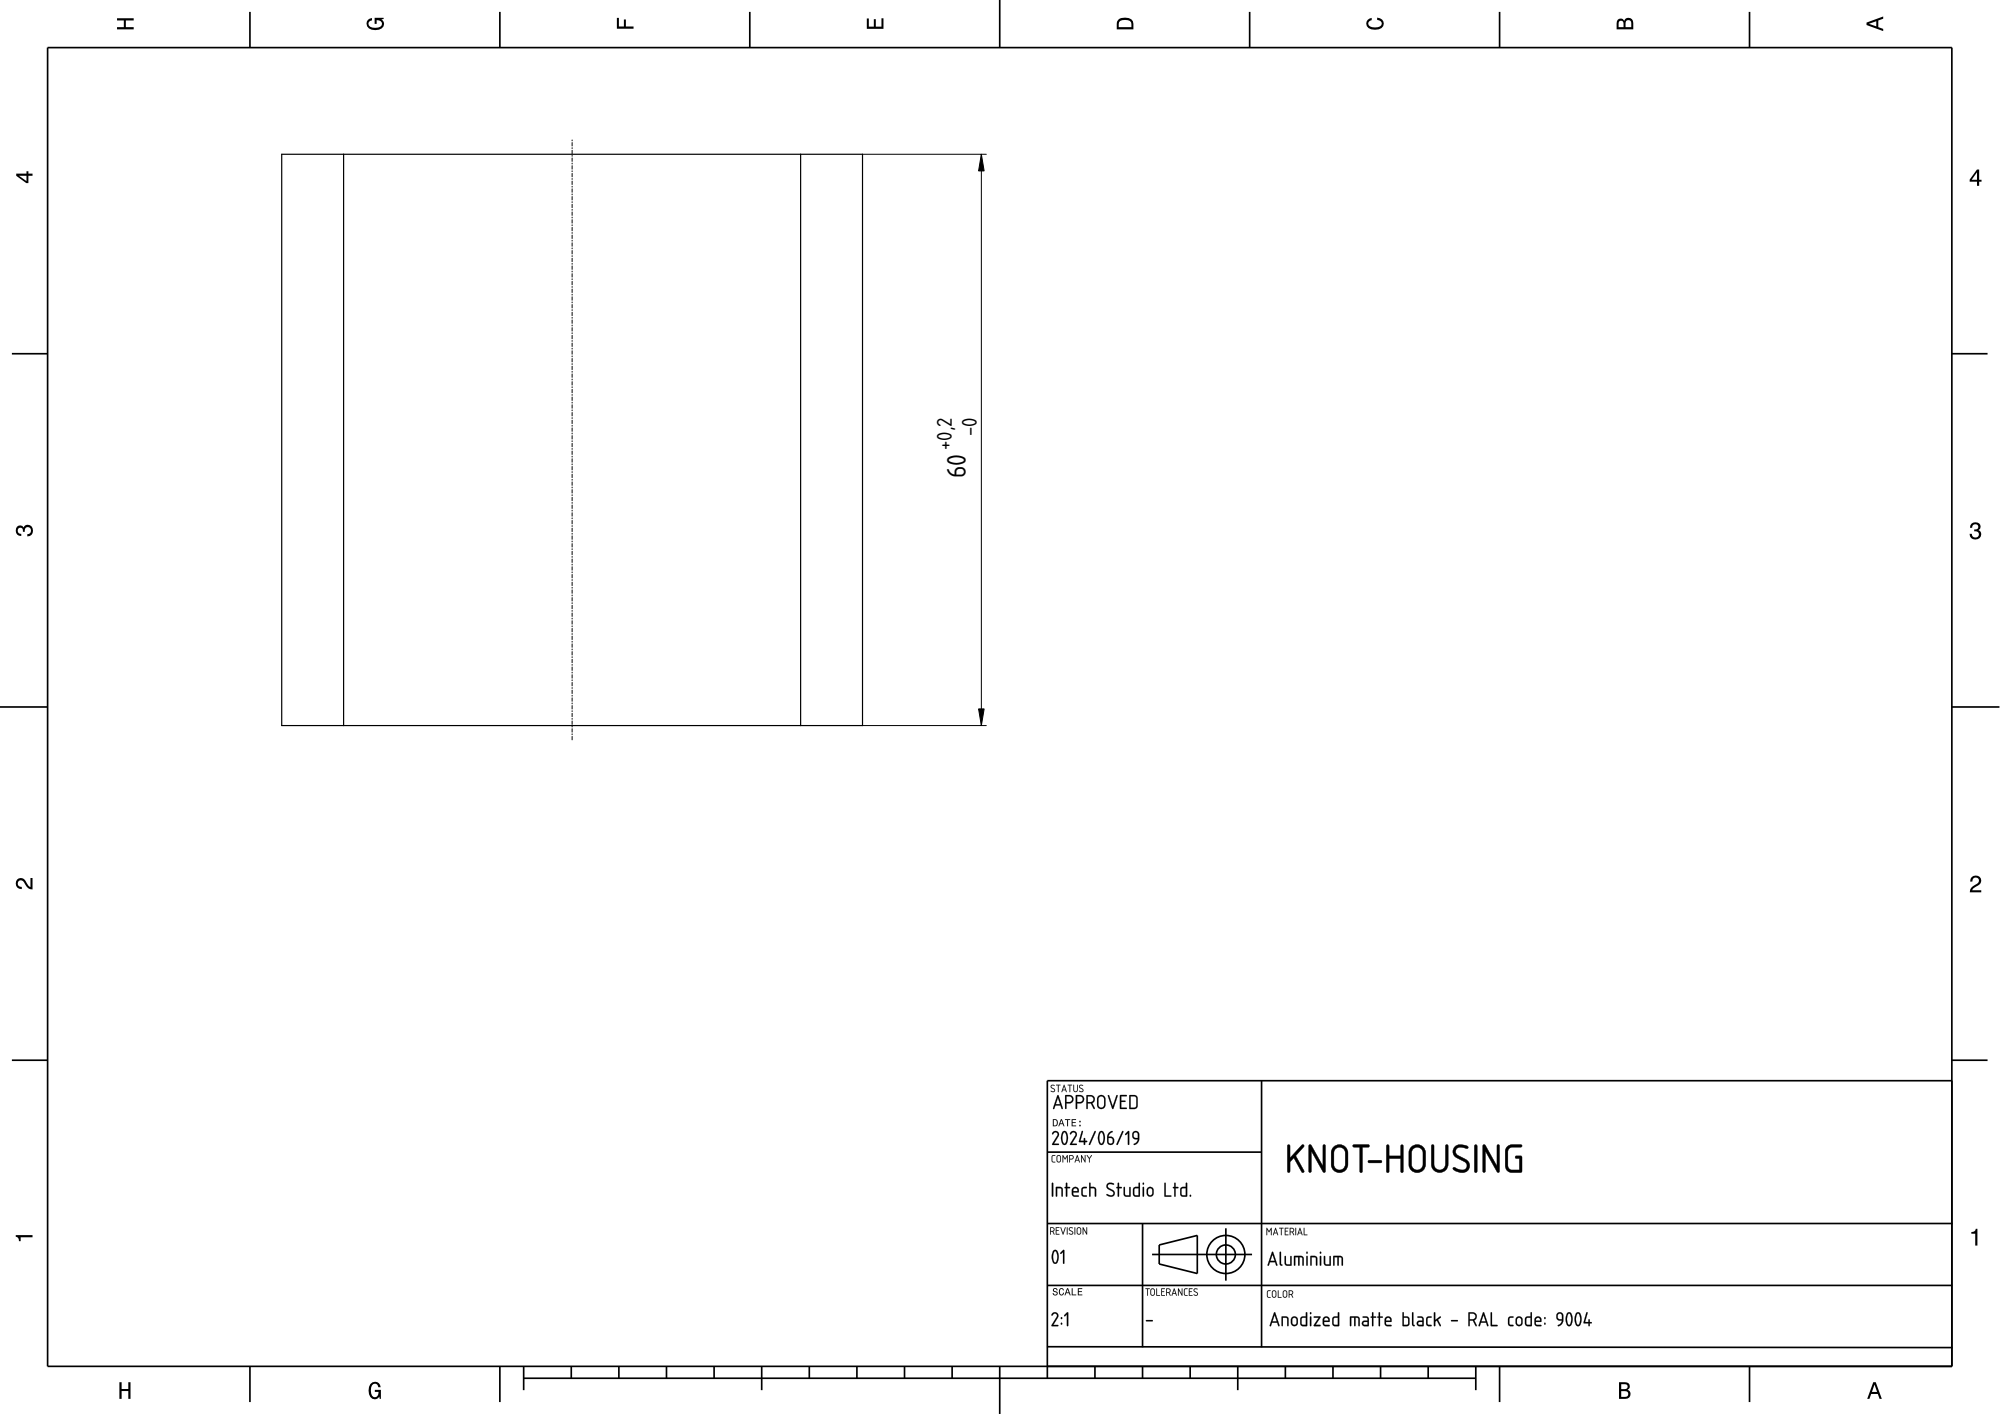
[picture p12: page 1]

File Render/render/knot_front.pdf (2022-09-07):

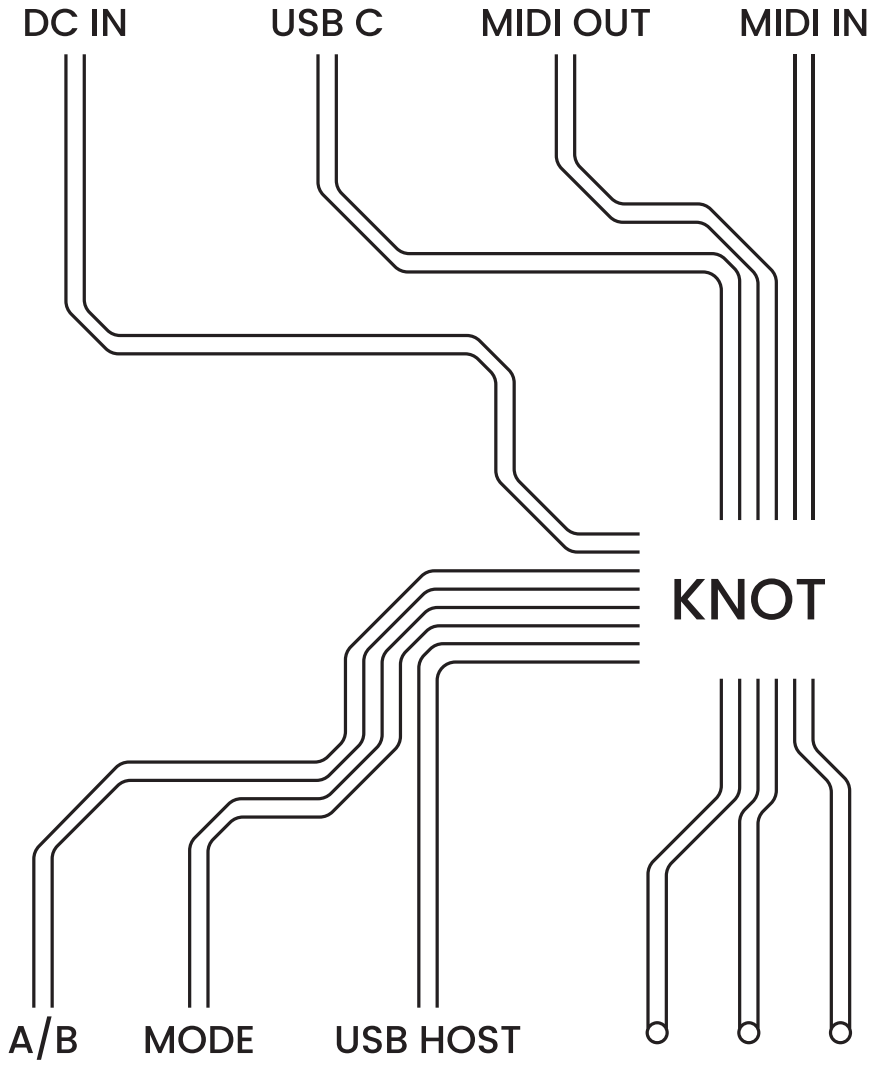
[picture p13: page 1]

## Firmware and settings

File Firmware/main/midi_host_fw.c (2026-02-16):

#ifdef TEST_CDC_SERIAL

/*
 * SPDX-FileCopyrightText: 2015-2023 Espressif Systems (Shanghai) CO LTD
 *
 * SPDX-License-Identifier: CC0-1.0
 */

#include "esp_err.h"
#include "esp_log.h"
#include "esp_system.h"
#include <inttypes.h>
#include <stdio.h>
#include <string.h>

#include "freertos/FreeRTOS.h"
#include "freertos/semphr.h"
#include "freertos/task.h"

#include "usb/cdc_acm_host.h"
#include "usb/usb_host.h"

#define EXAMPLE_USB_HOST_PRIORITY (20)
#define EXAMPLE_USB_DEVICE_VID (0x303A)
#define EXAMPLE_USB_DEVICE_PID (0x8123)      // 0x303A:0x4001 (TinyUSB CDC device)
#define EXAMPLE_USB_DEVICE_DUAL_PID (0x4002) // 0x303A:0x4002 (TinyUSB Dual CDC device)
#define EXAMPLE_TX_STRING ("CDC test string!")
#define EXAMPLE_TX_TIMEOUT_MS (1000)

static const char* TAG = "USB-CDC";
static SemaphoreHandle_t device_disconnected_sem;

/**
 * @brief Data received callback
 *
 * @param[in] data     Pointer to received data
 * @param[in] data_len Length of received data in bytes
 * @param[in] arg      Argument we passed to the device open function
 * @return
 *   true:  We have processed the received data
 *   false: We expect more data
 */
static bool handle_rx(const uint8_t* data, size_t data_len, void* arg) {
  ESP_LOGI(TAG, "Data received");
  ESP_LOG_BUFFER_HEXDUMP(TAG, data, data_len, ESP_LOG_INFO);
  return true;
}

/**
 * @brief Device event callback
 *
 * Apart from handling device disconnection it doesn't do anything useful
 *
 * @param[in] event    Device event type and data
 * @param[in] user_ctx Argument we passed to the device open function
 */
static void handle_event(const cdc_acm_host_dev_event_data_t* event, void* user_ctx) {
  switch (event->type) {
  case CDC_ACM_HOST_ERROR:
    ESP_LOGE(TAG, "CDC-ACM error has occurred, err_no = %i", event->data.error);
    break;
  case CDC_ACM_HOST_DEVICE_DISCONNECTED:
    ESP_LOGI(TAG, "Device suddenly disconnected");
    ESP_ERROR_CHECK(cdc_acm_host_close(event->data.cdc_hdl));
    xSemaphoreGive(device_disconnected_sem);
    break;
  case CDC_ACM_HOST_SERIAL_STATE:
    ESP_LOGI(TAG, "Serial state notif 0x%04X", event->data.serial_state.val);
    break;
  case CDC_ACM_HOST_NETWORK_CONNECTION:
  default:
    ESP_LOGW(TAG, "Unsupported CDC event: %i", event->type);
    break;
  }
}

/**
 * @brief USB Host library handling task
 *
 * @param arg Unused
 */
static void usb_lib_task(void* arg) {
  while (1) {
    // Start handling system events
    uint32_t event_flags;
    usb_host_lib_handle_events(portMAX_DELAY, &event_flags);
    if (event_flags & USB_HOST_LIB_EVENT_FLAGS_NO_CLIENTS) {
      ESP_ERROR_CHECK(usb_host_device_free_all());
    }
    if (event_flags & USB_HOST_LIB_EVENT_FLAGS_ALL_FREE) {
      ESP_LOGI(TAG, "USB: All devices freed");
      // Continue handling USB events to allow device reconnection
    }
  }
}

/**
 * @brief Main application
 *
 * Here we open a USB CDC device and send some data to it
 */

#include "driver/gpio.h"

void app_main(void) {

#define USB_NATIVE_SELECT_PIN 11
#define USB_SOFT_SELECT_PIN 12

  gpio_set_direction(USB_NATIVE_SELECT_PIN, GPIO_MODE_OUTPUT);
  gpio_set_direction(USB_SOFT_SELECT_PIN, GPIO_MODE_OUTPUT);
  gpio_set_level(USB_NATIVE_SELECT_PIN, 1);
  gpio_set_level(USB_SOFT_SELECT_PIN, 1);

#define PMIC_EN_PIN 48

  gpio_set_direction(PMIC_EN_PIN, GPIO_MODE_OUTPUT);
  gpio_set_level(PMIC_EN_PIN, 1);

  device_disconnected_sem = xSemaphoreCreateBinary();
  assert(device_disconnected_sem);

  // Install USB Host driver. Should only be called once in entire application
  ESP_LOGI(TAG, "Installing USB Host");
  const usb_host_config_t host_config = {
      .skip_phy_setup = false,
      .intr_flags = ESP_INTR_FLAG_LEVEL1,
  };
  ESP_ERROR_CHECK(usb_host_install(&host_config));

  // Create a task that will handle USB library events
  BaseType_t task_created = xTaskCreate(usb_lib_task, "usb_lib", 4096, xTaskGetCurrentTaskHandle(), EXAMPLE_USB_HOST_PRIORITY, NULL);
  assert(task_created == pdTRUE);

  ESP_LOGI(TAG, "Installing CDC-ACM driver");
  ESP_ERROR_CHECK(cdc_acm_host_install(NULL));

  const cdc_acm_host_device_config_t dev_config = {.connection_timeout_ms = 1000, .out_buffer_size = 512, .in_buffer_size = 512, .user_arg = NULL, .event_cb = handle_event, .data_cb = handle_rx};

  while (true) {
    cdc_acm_dev_hdl_t cdc_dev = NULL;

    // Open USB device from tusb_serial_device example example. Either single or dual port configuration.
    ESP_LOGI(TAG, "Opening CDC ACM device 0x%04X:0x%04X...", EXAMPLE_USB_DEVICE_VID, EXAMPLE_USB_DEVICE_PID);
    esp_err_t err = cdc_acm_host_open(EXAMPLE_USB_DEVICE_VID, EXAMPLE_USB_DEVICE_PID, 0, &dev_config, &cdc_dev);
    if (ESP_OK != err) {
      ESP_LOGI(TAG, "Opening CDC ACM device 0x%04X:0x%04X...", EXAMPLE_USB_DEVICE_VID, EXAMPLE_USB_DEVICE_DUAL_PID);
      err = cdc_acm_host_open(EXAMPLE_USB_DEVICE_VID, EXAMPLE_USB_DEVICE_DUAL_PID, 0, &dev_config, &cdc_dev);
      if (ESP_OK != err) {
        ESP_LOGI(TAG, "Failed to open device");
        continue;
      }
    }
    cdc_acm_host_desc_print(cdc_dev);
    vTaskDelay(pdMS_TO_TICKS(100));

    // Test sending and receiving: responses are handled in handle_rx callback
    ESP_ERROR_CHECK(cdc_acm_host_data_tx_blocking(cdc_dev, (const uint8_t*)EXAMPLE_TX_STRING, strlen(EXAMPLE_TX_STRING), EXAMPLE_TX_TIMEOUT_MS));
    vTaskDelay(pdMS_TO_TICKS(100));

    // Test Line Coding commands: Get current line coding, change it 9600 7N1 and read again
    ESP_LOGI(TAG, "Setting up line coding");

    cdc_acm_line_coding_t line_coding;
    ESP_ERROR_CHECK(cdc_acm_host_line_coding_get(cdc_dev, &line_coding));
    ESP_LOGI(TAG, "Line Get: Rate: %" PRIu32 ", Stop bits: %" PRIu8 ", Parity: %" PRIu8 ", Databits: %" PRIu8 "", line_coding.dwDTERate, line_coding.bCharFormat, line_coding.bParityType,
             line_coding.bDataBits);

    line_coding.dwDTERate = 9600;
    line_coding.bDataBits = 7;
    line_coding.bParityType = 1;
    line_coding.bCharFormat = 1;
    ESP_ERROR_CHECK(cdc_acm_host_line_coding_set(cdc_dev, &line_coding));
    ESP_LOGI(TAG, "Line Set: Rate: %" PRIu32 ", Stop bits: %" PRIu8 ", Parity: %" PRIu8 ", Databits: %" PRIu8 "", line_coding.dwDTERate, line_coding.bCharFormat, line_coding.bParityType,
             line_coding.bDataBits);

    ESP_ERROR_CHECK(cdc_acm_host_line_coding_get(cdc_dev, &line_coding));
    ESP_LOGI(TAG, "Line Get: Rate: %" PRIu32 ", Stop bits: %" PRIu8 ", Parity: %" PRIu8 ", Databits: %" PRIu8 "", line_coding.dwDTERate, line_coding.bCharFormat, line_coding.bParityType,
             line_coding.bDataBits);

    ESP_ERROR_CHECK(cdc_acm_host_set_control_line_state(cdc_dev, true, false));

    // We are done. Wait for device disconnection and start over
    ESP_LOGI(TAG, "Example finished successfully! You can reconnect the device to run again.");
    xSemaphoreTake(device_disconnected_sem, portMAX_DELAY);
  }
}

#else

#include "esp_intr_alloc.h"
#include "esp_log.h"

#include "freertos/FreeRTOS.h"
#include "freertos/semphr.h"
#include "freertos/task.h"
#include "usb/usb_host.h"

// must be last freertos relevant header to avoid #error
#include "esp_freertos_hooks.h"

#include <string.h>

#include "knot_midi_queue.h"
#include "knot_midi_uart.h"
#include "knot_midi_usb.h"

#include "grid_littlefs.h"
#include "grid_platform.h"

#define SW_AB_PIN 35
#define SW_MODE_PIN 36

#include "driver/gpio.h"

#define DAEMON_TASK_PRIORITY 3
#define CLASS_TASK_PRIORITY 4
#define LED_TASK_PRIORITY 2

#define UART_RX_TASK_PRIORITY 0
#define UART_TX_TASK_PRIORITY 0

#define USB_RX_TASK_PRIORITY 0
#define USB_TX_TASK_PRIORITY 0

static const char* TAG = "DAEMON";

void midi_config_file_update(uint8_t state) {

  ESP_LOGI(TAG, "midi_config_file_update, state: %d", state);

  const char data[1] = {state ? '1' : '0'};

  int status;

  status = grid_platform_write_file("midithrough.cfg", (uint8_t*)&data, 1);
  if (status) {
    grid_platform_printf("grid_platform_write_file returned %d\n", status);
    return;
  }
}

uint8_t midi_config_file_read(void) {

  ESP_LOGI(TAG, "midi_config_file_read");

  struct grid_file_t handle = {0};

  int status;

  status = grid_platform_find_file("midithrough.cfg", &handle);
  if (status) {
    grid_platform_printf("grid_platform_find_file returned %d\n", status);
    return 0;
  }

  char data[1];

  status = grid_platform_read_file(&handle, (uint8_t*)&data, 1);
  if (status) {
    grid_platform_printf("grid_platform_read_file returned %d\n", status);
    return 0;
  }

  if (data[0] != '0' && data[0] != '1') {
    grid_platform_printf("the first character in the file is not 0 or 1\n", data[0]);
    return 0;
  }

  grid_platform_printf("the first character in the file is: %c\n", data[0]);

  return data[0] - '0';
}

static void host_lib_daemon_task(void* arg) {
  SemaphoreHandle_t signaling_sem = (SemaphoreHandle_t)arg;

  ESP_LOGI(TAG, "Installing USB Host Library");
  usb_host_config_t host_config = {
      .skip_phy_setup = false,
      .intr_flags = ESP_INTR_FLAG_LEVEL1,
  };
  ESP_ERROR_CHECK(usb_host_install(&host_config));

  // Signal to the class driver task that the host library is installed
  xSemaphoreGive(signaling_sem);
  vTaskDelay(10); // Short delay to let client task spin up

  bool has_clients = true;
  bool has_devices = true;
  while (has_clients || has_devices) {
    uint32_t event_flags;
    ESP_ERROR_CHECK(usb_host_lib_handle_events(portMAX_DELAY, &event_flags));
    if (event_flags & USB_HOST_LIB_EVENT_FLAGS_NO_CLIENTS) {
      // has_clients = false;
    }
    if (event_flags & USB_HOST_LIB_EVENT_FLAGS_ALL_FREE) {
      // has_devices = false;
    }
    ESP_LOGI(TAG, "Event: %ld", event_flags);
    portYIELD();
  }
  ESP_LOGI(TAG, "No more clients and devices");

  // Uninstall the USB Host Library
  ESP_ERROR_CHECK(usb_host_uninstall());
  // Wait to be deleted
  xSemaphoreGive(signaling_sem);
  vTaskSuspend(NULL);
}

#include "rom/ets_sys.h" // For ets_printf
void grid_platform_printf(char const* fmt, ...) {

  va_list ap;

  char temp[200] = {0};

  va_start(ap, fmt);

  vsnprintf(temp, 199, fmt, ap);

  va_end(ap);

  ets_printf(temp);
}

#include "knot_platform.h"

#include "grid_ain.h"
#include "grid_led.h"
#include "grid_lua.h"
#include "grid_ui.h"
#include "grid_ui_system.h"

#include "grid_esp32_led.h"
#include "grid_esp32_nvm.h"

void knot_lua_ui_init(struct grid_lua_model* lua) {

  struct grid_ui_model* ui = &grid_ui_state;

  grid_lua_create_element_array(lua->L, ui->element_list_length);

  for (int i = 0; i < ui->element_list_length; ++i) {

    struct grid_ui_element* ele = grid_ui_element_find(&grid_ui_state, i);

    if (ele->type == GRID_PARAMETER_ELEMENT_SYSTEM) {
      grid_lua_dostring_unsafe(lua, GRID_LUA_S_META_init);
      grid_lua_register_index_meta_for_type(lua->L, GRID_LUA_S_TYPE, GRID_LUA_S_INDEX_META);
    }

    grid_lua_register_element(lua->L, i);
    grid_lua_register_index_meta_for_element(lua->L, i, GRID_LUA_S_TYPE);
  }
}

void knot_module_ui_init(struct grid_ain_model* ain, struct grid_led_model* led, struct grid_ui_model* ui) {

  grid_led_init(led, 3);
  grid_ui_model_init(ui, 0 + 1); // +1 for the system element

  grid_ui_element_system_init(&ui->element_list[ui->element_list_length - 1]);

  ui->lua_ui_init_callback = knot_lua_ui_init;
}

extern esp_err_t try_start_in_transfer(void);

bool idle_hook(void) {

  portYIELD();
  return 0; // return 1 causes one trigger / rtos tick
}

void app_main(void) {

  // Configure task timers
  struct grid_utask_timer timer_led = (struct grid_utask_timer){
      .last = grid_platform_rtc_get_micros(),
      .period = 9500, // 10000 really, but FreeRTOS is currently 100 Hz
  };

  // MIDI A/B SWITCH AND THROUGH BUTTON INTERACTIVITY
  gpio_set_direction(SW_AB_PIN, GPIO_MODE_INPUT);
  gpio_pullup_en(SW_AB_PIN);
  gpio_set_direction(SW_MODE_PIN, GPIO_MODE_INPUT);

  SemaphoreHandle_t nvm_or_port = xSemaphoreCreateBinary();
  xSemaphoreGive(nvm_or_port);

  ESP_LOGI(TAG, "===== MAIN START =====");

  // gpio_set_direction(GRID_ESP32_PINS_MAPMODE, GPIO_MODE_INPUT);
  // gpio_pullup_en(GRID_ESP32_PINS_MAPMODE);

  ESP_LOGI(TAG, "===== SYS START =====");
  // grid_sys_init(&grid_sys_state);

  ESP_LOGI(TAG, "===== UI INIT =====");

  knot_module_ui_init(&grid_ain_state, &grid_led_state, &grid_ui_state);
  grid_led_set_pin(&grid_led_state, 1);

  grid_led_set_layer_color(&grid_led_state, 0, 0, 0, 0, 0);
  grid_led_set_layer_color(&grid_led_state, 1, 0, 0, 0, 0);
  grid_led_set_layer_color(&grid_led_state, 2, 0, 0, 0, 0);

  grid_led_set_layer_color(&grid_led_state, 0, 1, 0, 0, 0);
  grid_led_set_layer_color(&grid_led_state, 1, 1, 0, 0, 0);
  grid_led_set_layer_color(&grid_led_state, 2, 1, 0, 0, 0);

  grid_led_set_layer_color(&grid_led_state, 0, 2, 0, 0, 0);
  grid_led_set_layer_color(&grid_led_state, 1, 2, 0, 0, 0);
  grid_led_set_layer_color(&grid_led_state, 2, 2, 0, 0, 0);

  grid_esp32_led_start(grid_led_get_pin(&grid_led_state));

  ESP_LOGI(TAG, "===== NVM START =====");

  xSemaphoreTake(nvm_or_port, 0);
  grid_esp32_nvm_mount(&grid_esp32_nvm_state, false);

  if (gpio_get_level(SW_MODE_PIN) == 0) {

    grid_alert_all_set(&grid_led_state, GRID_LED_COLOR_YELLOW_DIM, 1000);
    grid_alert_all_set_frequency(&grid_led_state, 4);
    grid_platform_nvm_format_and_mount();
    vTaskDelay(pdMS_TO_TICKS(1600));
  }

  xSemaphoreGive(nvm_or_port);

  ESP_LOGI(TAG, "===== LUA INIT =====");
  grid_lua_init(&grid_lua_state, NULL, NULL);
  grid_lua_set_memory_target(&grid_lua_state, 80); // 80kb
  grid_lua_start_vm(&grid_lua_state, &(struct luaL_Reg){NULL, NULL}, grid_ui_state.lua_ui_init_callback);

#define USB_NATIVE_SELECT_PIN 11
#define USB_SOFT_SELECT_PIN 12

  gpio_set_direction(USB_NATIVE_SELECT_PIN, GPIO_MODE_OUTPUT);
  gpio_set_direction(USB_SOFT_SELECT_PIN, GPIO_MODE_OUTPUT);
  gpio_set_level(USB_NATIVE_SELECT_PIN, 1);
  gpio_set_level(USB_SOFT_SELECT_PIN, 1);

#define PMIC_EN_PIN 48

  gpio_set_direction(PMIC_EN_PIN, GPIO_MODE_OUTPUT);
  gpio_set_level(PMIC_EN_PIN, 1);

  SemaphoreHandle_t signaling_sem = xSemaphoreCreateBinary();

  TaskHandle_t daemon_task_hdl;
  TaskHandle_t class_driver_task_hdl;

  TaskHandle_t uart_rx_task_hdl;
  TaskHandle_t uart_tx_task_hdl;
  TaskHandle_t uart_housekeeping_task_hdl;
  // Create daemon task
  xTaskCreatePinnedToCore(host_lib_daemon_task, "daemon", 4096, (void*)signaling_sem, DAEMON_TASK_PRIORITY, &daemon_task_hdl, 1);
  // Create the class driver task
  xTaskCreatePinnedToCore(class_driver_task, "class", 4096, (void*)signaling_sem, CLASS_TASK_PRIORITY, &class_driver_task_hdl, 1);

  // Create a task to handler UART event from ISR

  vTaskDelay(10); // Add a short delay to let the tasks run

  knot_midi_uart_init(&knot_midi_uart_state);

  grid_platform_list_directory("");

  if (midi_config_file_read()) {
    ESP_LOGI(TAG, "Midi through enabled");
    knot_midi_uart_set_midithrough_state(&knot_midi_uart_state, true);
    grid_led_set_layer_color(&grid_led_state, 2, GRID_LED_LAYER_UI_A, 0, 0, 255); // blue
  } else {
    ESP_LOGI(TAG, "Midi through disabled");
    knot_midi_uart_set_midithrough_state(&knot_midi_uart_state, false);
    grid_led_set_layer_color(&grid_led_state, 2, GRID_LED_LAYER_UI_A, 0, 255, 0); // green
  }

  xTaskCreatePinnedToCore(knot_midi_uart_rx_task, "uart_rx", 4096, (void*)signaling_sem, UART_RX_TASK_PRIORITY, &uart_rx_task_hdl, 1);
  xTaskCreatePinnedToCore(knot_midi_uart_tx_task, "uart_tx", 4096, (void*)signaling_sem, UART_TX_TASK_PRIORITY, &uart_tx_task_hdl, 1);

  xTaskCreatePinnedToCore(knot_midi_usb_rx_task, "usb_rx", 4096, (void*)signaling_sem, USB_RX_TASK_PRIORITY, &uart_rx_task_hdl, 1);
  xTaskCreatePinnedToCore(knot_midi_usb_tx_task, "usb_tx", 4096, (void*)signaling_sem, USB_TX_TASK_PRIORITY, &uart_tx_task_hdl, 1);

  // Register idle hook to force yield from idle task to lowest priority task
  esp_register_freertos_idle_hook_for_cpu(idle_hook, 0);
  esp_register_freertos_idle_hook_for_cpu(idle_hook, 1);

  uint8_t last_button_state = 1;

  UBaseType_t highwatermark = uxTaskGetStackHighWaterMark(xTaskGetCurrentTaskHandle());
  ESP_LOGI(TAG, "highwatermark before main loop: %d", highwatermark);

  while (1) {

    vTaskDelay(pdMS_TO_TICKS(10));

    grid_esp32_utask_led(&timer_led);

    knot_midi_uart_set_miditrsab_state(&knot_midi_uart_state, !gpio_get_level(SW_AB_PIN));

    uint8_t current_button_state = gpio_get_level(SW_MODE_PIN);

    if (last_button_state == 1 && current_button_state == 0) {

      if (knot_midi_uart_get_midithrough_state(&knot_midi_uart_state)) {
        knot_midi_uart_set_midithrough_state(&knot_midi_uart_state, false);
        grid_led_set_layer_color(&grid_led_state, 2, GRID_LED_LAYER_UI_A, 0, 255, 0);
        midi_config_file_update(false);

      } else {
        knot_midi_uart_set_midithrough_state(&knot_midi_uart_state, true);
        grid_led_set_layer_color(&grid_led_state, 2, GRID_LED_LAYER_UI_A, 0, 0, 255);
        midi_config_file_update(true);
      }
    }

    last_button_state = current_button_state;
  }
}

#endif

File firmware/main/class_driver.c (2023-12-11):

/*
 * SPDX-FileCopyrightText: 2021-2022 Espressif Systems (Shanghai) CO LTD
 *
 * SPDX-License-Identifier: Unlicense OR CC0-1.0
 */

#include <stdlib.h>
#include <string.h>
#include "freertos/FreeRTOS.h"
#include "freertos/semphr.h"
#include "esp_log.h"
#include "usb/usb_host.h"
#include "grid_led.h"
#include "../managed_components/sukuwc__grid_common/grid_led.h"

#include "knot_midi_translator.h"

#include "rom/ets_sys.h" // For ets_printf

#define CLIENT_NUM_EVENT_MSG        5

#define ACTION_OPEN_DEV             0x01
#define ACTION_GET_DEV_INFO         0x02
#define ACTION_GET_DEV_DESC         0x04
#define ACTION_GET_CONFIG_DESC      0x08
#define ACTION_GET_STR_DESC         0x10
#define ACTION_CLOSE_DEV            0x20
#define ACTION_EXIT                 0x40

typedef struct {
    usb_host_client_handle_t client_hdl;
    uint8_t dev_addr;
    usb_device_handle_t dev_hdl;
    uint32_t actions;
    int claimed_interface;
} class_driver_t;





//extern void led_connect_effect_start(void);
//extern void led_disconnect_effect_start(void);

extern int uart_send_data(struct uart_midi_event_packet ev);


static const char *TAG = "CLASS";

static void client_event_cb(const usb_host_client_event_msg_t *event_msg, void *arg)
{

    class_driver_t *driver_obj = (class_driver_t *)arg;



    ets_printf("client event %d\r\n", event_msg->event);

    switch (event_msg->event) {
        case USB_HOST_CLIENT_EVENT_NEW_DEV:
            if (driver_obj->dev_addr == 0) {
                driver_obj->dev_addr = event_msg->new_dev.address;
                //Open the device next
                driver_obj->actions |= ACTION_OPEN_DEV;
            }
            break;
        case USB_HOST_CLIENT_EVENT_DEV_GONE:
            if (driver_obj->dev_hdl != NULL) {
                //Cancel any other actions and close the device next
                driver_obj->actions = ACTION_CLOSE_DEV;
            }
            break;
        default:
            //Should never occur
            abort();
    }
}

static void action_open_dev(class_driver_t *driver_obj)
{
    assert(driver_obj->dev_addr != 0);
    ESP_LOGI(TAG, "Opening device at address %d", driver_obj->dev_addr);
    ESP_ERROR_CHECK(usb_host_device_open(driver_obj->client_hdl, driver_obj->dev_addr, &driver_obj->dev_hdl));
    //Get the device's information next
    driver_obj->actions &= ~ACTION_OPEN_DEV;
    driver_obj->actions |= ACTION_GET_DEV_INFO;
}

static void action_get_info(class_driver_t *driver_obj)
{
    assert(driver_obj->dev_hdl != NULL);
    ESP_LOGI(TAG, "Getting device information");
    usb_device_info_t dev_info;
    ESP_ERROR_CHECK(usb_host_device_info(driver_obj->dev_hdl, &dev_info));
    ESP_LOGI(TAG, "\t%s speed", (dev_info.speed == USB_SPEED_LOW) ? "Low" : "Full");
    ESP_LOGI(TAG, "\tbConfigurationValue %d", dev_info.bConfigurationValue);
    //Todo: Print string descriptors

    //Get the device descriptor next
    driver_obj->actions &= ~ACTION_GET_DEV_INFO;
    driver_obj->actions |= ACTION_GET_DEV_DESC;
}


unsigned long loopcounter = 0;


static esp_err_t midi_find_intf_and_ep_desc(class_driver_t *driver_obj, const usb_ep_desc_t **in_ep, const usb_ep_desc_t **out_ep, int* intf_num)
{
    bool interface_found = false;
    const usb_config_desc_t *config_desc;
    const usb_device_desc_t *device_desc;
    int intf_idx = -1;    
    int desc_offset = 0;
    
    // Get required descriptors
    ESP_ERROR_CHECK(usb_host_get_device_descriptor(driver_obj->dev_hdl, &device_desc));
    ESP_ERROR_CHECK(usb_host_get_active_config_descriptor(driver_obj->dev_hdl, &config_desc));

    #define USB_SUBCLASS_NULL          0x00
    #define USB_SUBCLASS_COMMON        0x02

    #define USB_PROTOCOL_NULL           0x00
    #define USB_DEVICE_PROTOCOL_IAD    0x01

    if (((device_desc->bDeviceClass == USB_CLASS_MISC) && (device_desc->bDeviceSubClass == USB_SUBCLASS_COMMON) && (device_desc->bDeviceProtocol == USB_DEVICE_PROTOCOL_IAD)) ||
        ((device_desc->bDeviceClass == USB_CLASS_PER_INTERFACE) && (device_desc->bDeviceSubClass == USB_SUBCLASS_NULL) && (device_desc->bDeviceProtocol == USB_PROTOCOL_NULL))) {

        ESP_LOGI(TAG, "IAD");

        const usb_standard_desc_t *this_desc = (const usb_standard_desc_t *)config_desc;
        do {

            ESP_LOGI(TAG, "TRY");
            intf_idx++;

            this_desc = usb_parse_next_descriptor_of_type(
                this_desc, config_desc->wTotalLength, USB_B_DESCRIPTOR_TYPE_INTERFACE, &desc_offset);

            if (this_desc == NULL){
                ESP_LOGI(TAG, "INTERFACE NOT FOUND");
                break; // Reached end of configuration descriptor
            }

      

            const usb_intf_desc_t *intf_desc = (const usb_intf_desc_t *)this_desc;


            ESP_LOGI(TAG, "Interface %d %d %d %d", intf_desc->bInterfaceNumber, intf_desc->bInterfaceClass, intf_desc->bInterfaceSubClass, intf_desc->bInterfaceProtocol);      
            
            #define USB_SUBCLASS_MIDISTREAMING 0x03
            if (intf_desc->bInterfaceClass == USB_CLASS_AUDIO && intf_desc->bInterfaceSubClass == USB_SUBCLASS_MIDISTREAMING && intf_desc->bInterfaceProtocol == 0x00){

                ESP_LOGI(TAG, "MIDI INTERFACE FOUND %d", intf_desc->bInterfaceNumber);
                *intf_num = intf_desc->bInterfaceNumber;
                interface_found = true;

            }
            
        } while (!interface_found);


        if (interface_found){


            usb_intf_desc_t* intf_desc = usb_parse_interface_descriptor(config_desc, *intf_num, 0, &desc_offset);

            ESP_LOGI(TAG, "wTotal, offset: 0x%lx %d %d", (unsigned long int) intf_desc, config_desc->wTotalLength, desc_offset);


            int temp_offset = desc_offset;
            for (int i = 0; i < 2; i++) {
                const usb_ep_desc_t *this_ep = usb_parse_endpoint_descriptor_by_index(intf_desc, i, config_desc->wTotalLength, &desc_offset);
                assert(this_ep);
                if (USB_EP_DESC_GET_EP_DIR(this_ep)) {
                    *in_ep = this_ep;
                    ESP_LOGI(TAG, "IN EP FOUND %d", this_ep->bEndpointAddress);
                } else {
                    *out_ep = this_ep;
                    ESP_LOGI(TAG, "OUT EP FOUND %d", this_ep->bEndpointAddress);
                }
                desc_offset = temp_offset;
            }

            return ESP_OK;

        }
    } 
    else{
        ESP_LOGI(TAG, "NOT IAD");

             const usb_standard_desc_t *this_desc = (const usb_standard_desc_t *)config_desc;
        do {

            ESP_LOGI(TAG, "TRY");
            intf_idx++;

            this_desc = usb_parse_next_descriptor_of_type(
                this_desc, config_desc->wTotalLength, USB_B_DESCRIPTOR_TYPE_INTERFACE, &desc_offset);

            if (this_desc == NULL){
                ESP_LOGI(TAG, "INTERFACE NOT FOUND");
                break; // Reached end of configuration descriptor
            }
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

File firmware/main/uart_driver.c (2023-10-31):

/*
 * SPDX-FileCopyrightText: 2021-2022 Espressif Systems (Shanghai) CO LTD
 *
 * SPDX-License-Identifier: Unlicense OR CC0-1.0
 */

#include <stdlib.h>
#include <string.h>
#include "freertos/FreeRTOS.h"
#include "freertos/semphr.h"
#include "freertos/ringbuf.h"
#include "esp_log.h"
#include "esp_system.h"

#include "driver/gpio.h"

#include "rom/ets_sys.h" // For ets_printf

#include "freertos/queue.h"
#include "driver/uart.h"
#include "midi_translator.h"


#define EX_UART_NUM UART_NUM_1
#define PATTERN_CHR_NUM    (3)         /*!< Set the number of consecutive and identical characters received by receiver which defines a UART pattern*/

#define BUF_SIZE (1024)
#define RD_BUF_SIZE (BUF_SIZE)
static QueueHandle_t uart0_queue;

static const char *TAG = "UART";

uint8_t midi_through = false;

#include "driver/gpio.h"

#include "grid_led.h"
#include "../managed_components/sukuwc__grid_common/grid_led.h"

#define TRS_TX_AB_SELECT 15
#define TRS_RX_AB_SELECT 16
#define SW_AB_PIN 35
#define SW_MODE_PIN 36



RingbufHandle_t uart_rx_buffer_cvm;
RingbufHandle_t uart_rx_buffer_rtm;

uint8_t current_is_sysex = 0;

//extern void led_tx_effect_start(void);
//extern void led_rx_effect_start(void);
//extern void led_err_effect_start(void);
extern void usb_midi_packet_send(struct usb_midi_event_packet ev);

void uart_init(){


    ESP_LOGI(TAG, "UART init");

    esp_log_level_set(TAG, ESP_LOG_INFO);

    /* Configure parameters of an UART driver,
     * communication pins and install the driver */
    uart_config_t uart_config = {
        .baud_rate = 31250,
        .data_bits = UART_DATA_8_BITS,
        .parity = UART_PARITY_DISABLE,
        .stop_bits = UART_STOP_BITS_1,
        .flow_ctrl = UART_HW_FLOWCTRL_DISABLE,
        .source_clk = UART_SCLK_DEFAULT,
    };
    //Install UART driver, and get the queue.
    uart_driver_install(EX_UART_NUM, BUF_SIZE * 2, BUF_SIZE * 2, 20, &uart0_queue, 0);
    uart_param_config(EX_UART_NUM, &uart_config);

    //Set UART log level
    esp_log_level_set(TAG, ESP_LOG_INFO);
    //Set UART pins (using UART0 default pins ie no changes.)
    uart_set_pin(EX_UART_NUM, UART_PIN_NO_CHANGE, UART_PIN_NO_CHANGE, UART_PIN_NO_CHANGE, UART_PIN_NO_CHANGE);
    uart_set_pin(EX_UART_NUM, 17, 18, UART_PIN_NO_CHANGE, UART_PIN_NO_CHANGE);

    uart_set_line_inverse(EX_UART_NUM, UART_SIGNAL_TXD_INV);

    //Set uart pattern detect function.
    uart_enable_pattern_det_baud_intr(EX_UART_NUM, '+', PATTERN_CHR_NUM, 9, 0, 0);
    //Reset the pattern queue length to record at most 20 pattern positions.
    uart_pattern_queue_reset(EX_UART_NUM, 20);


    gpio_set_direction(SW_AB_PIN, GPIO_MODE_INPUT);
    gpio_set_direction(SW_MODE_PIN, GPIO_MODE_INPUT);

    gpio_set_direction(TRS_TX_AB_SELECT, GPIO_MODE_OUTPUT);
    // gpio_set_direction(TRS_RX_AB_SELECT, GPIO_MODE_OUTPUT);

    
    //gpio_set_level(TRS_TX_AB_SELECT, gpio_get_level(SW_AB_PIN));
    gpio_set_level(TRS_TX_AB_SELECT, !gpio_get_level(SW_AB_PIN));



    // Channel Voice Message Buffer
    #define UART_RX_BUFFER_CVM_SIZE 1600
    uart_rx_buffer_cvm = xRingbufferCreate(UART_RX_BUFFER_CVM_SIZE, RINGBUF_TYPE_NOSPLIT);
    if (uart_rx_buffer_cvm == NULL) {
        ets_printf("Failed to create ring buffer\n");
    }

    // Real-Time Message Buffer
    #define UART_RX_BUFFER_RTM_SIZE 20
    uart_rx_buffer_rtm = xRingbufferCreate(UART_RX_BUFFER_RTM_SIZE, RINGBUF_TYPE_NOSPLIT);
    if (uart_rx_buffer_rtm == NULL) {
        ets_printf("Failed to create ring buffer\n");
    }

}


int uart_send_data(struct uart_midi_event_packet ev)
{

    grid_alert_one_set(&grid_led_state, 1, 100, 100, 100, 30);



    //led_tx_effect_start();

    const int txBytes = uart_write_bytes(EX_UART_NUM, &ev.byte1, ev.length);
    //printf("MIDI: %d : %d %d %d\n", ev.length, ev.byte1, ev.byte2, ev.byte3);
    //ESP_LOGI(logName, "Wrote %d bytes %d %d %d", txBytes, data[0], data[1], data[2]);
    return txBytes;
}


void uart_housekeeping_task(void *arg){



    SemaphoreHandle_t signaling_sem = (SemaphoreHandle_t)arg;
    //xSemaphoreTake(signaling_sem, portMAX_DELAY);

    ESP_LOGI(TAG, "UART TX init done");

    uint8_t last_button_state = 1;
    grid_led_set_layer_color(&grid_led_state, 2, GRID_LED_LAYER_UI_A, 0, 100, 0);

    for(;;) {
    

        vTaskDelay(pdMS_TO_TICKS(10));

        //gpio_set_level(TRS_TX_AB_SELECT, gpio_get_level(SW_AB_PIN));
        gpio_set_level(TRS_TX_AB_SELECT, !gpio_get_level(SW_AB_PIN));



        uint8_t current_button_state = gpio_get_level(SW_MODE_PIN);

        if (last_button_state == 1 && current_button_state == 0){

            if (midi_through){
                midi_through = 0;
                grid_led_set_layer_color(&grid_led_state, 2, GRID_LED_LAYER_UI_A, 0, 100, 0);
            }
            else{
                midi_through = 1;
                grid_led_set_layer_color(&grid_led_state, 2, GRID_LED_LAYER_UI_A, 0, 0, 100);
            }
        }

        last_button_state = current_button_state;

    }
}
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

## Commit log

2022-07-23 SUKU kicad project imported
    [MIDI_Host.kicad_pcb, MIDI_Host.kicad_sch, MIDI_Host.step]
2022-07-23 SUKU mechanical assembly imported
    [MIDI_Host_assembly.FCStd, untitled.stl]
2022-07-29 SUKU host devboard created, cicd added
    [MIDI_Host.kicad_pcb, MIDI_Host.kicad_sch, MIDI_Host.step]
2022-07-29 SUKU nc flags added to unused pins
    [MIDI_Host.kicad_sch]
2022-08-06 SUKU schematic progress
    [MIDI_Host.kicad_pcb, MIDI_Host.kicad_sch, midi.kicad_sch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]
2022-08-09 SUKU sch done
    [MIDI_Host.kicad_pcb, MIDI_Host.kicad_sch, midi.kicad_sch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]
2022-08-09 SUKU tht components included in pos file
    [MIDI_Host.kicad_pcb, MIDI_Host.kicad_sch]
2022-08-09 SUKU unconnected label removed
    [MIDI_Host.kicad_sch]
2022-08-09 SUKU design quick-routed
    [MIDI_Host.kicad_pcb]
2022-08-11 SUKU sync
    [MIDI_Host.kicad_sch, midi.kicad_sch, power.kicad_sch]
2022-08-18 SUKU successful enumeration and MIDI out test
    [MIDI_Host.kicad_pcb, MIDI_Host.kicad_sch]
2022-08-22 SUKU Midi host initial design + layout done
    [MIDI_Host.kicad_pcb, MIDI_Host.kicad_sch, midi.kicad_sch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]
2022-08-22 SUKU dangling wire in schematic removed
    [MIDI_Host.kicad_sch, power.kicad_sch]
2022-08-22 SUKU DRC errors fixed
    [MIDI_Host.kicad_pcb]
2022-08-22 SUKU resistor values added
    [MIDI_Host.kicad_pcb, MIDI_Host.kicad_sch, midi.kicad_sch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]
2022-08-24 SUKU ws2812 lib and test added
    [MIDI_Host.kicad_pcb]
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2022-09-05 SUKU mechanical exports added
    [MIDI_Host.kicad_pcb, MIDI_Host.kicad_sch, MIDI_Host_assembly-Alu.stl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]
2022-09-05 SUKU hardware definitions updated to use new proto, midi tx led function implemented
2022-09-05 SUKU front and back plates updated
    [MIDI_Host_assembly.FCStd]
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2022-09-07 SUKU midi rx indicator added, partition table fixed
    [partitions-8MB.csv]
2022-09-08 SUKU pcb revision done
    [MIDI_Host.kicad_pcb, MIDI_Host.kicad_sch, midi.kicad_sch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]
2022-09-08 SUKU capacitor footprint fixed,packup placement added
    [MIDI_Host.kicad_pcb, MIDI_Host.kicad_sch, midi.kicad_sch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]
2022-09-08 SUKU frontpanel and backpabnel designed
    [MIDI_Host_assembly.FCStd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]
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2022-10-10 SUKU sync + fw connect status led function added
    [MIDI_Host.kicad_pcb, MIDI_Host.kicad_sch, MIDI_Host_assembly.FCStd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]
2022-10-13 SUKU connectors moved back, gerber testpoint names fixed
    [MIDI_Host.kicad_pcb, MIDI_Host.kicad_sch, midi.kicad_sch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]
2022-10-17 SUKU v3 laout finished, decoupling and esd protection improved
    [MIDI_Host.kicad_pcb, MIDI_Host.kicad_sch, midi.kicad_sch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]
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2022-11-09 SUKU PCB sync
    [MIDI_Host.kicad_pcb, MIDI_Host_assembly-Front2.step, MIDI_Host_assembly.FCStd]
2022-11-10 SUKU syncnc
    [MIDI_Host.kicad_pcb]
2022-11-14 SUKU design files organized
    [MIDI_Host_assembly-Alu.stl, MIDI_Host_assembly-Back.stl, MIDI_Host_assembly-Front.stl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]
2022-11-17 SUKU outline updated
    [MIDI_Host.kicad_pcb]
2022-11-18 SUKU PMIC enable pin signal added
    [MIDI_Host.kicad_pcb, MIDI_Host.kicad_sch, power.kicad_sch]
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2023-03-24 SUKU capacitor footprint updated
    [MIDI_Host.kicad_pcb, MIDI_Host.kicad_sch, midi.kicad_sch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]
2023-03-28 SUKU output origin set
    [MIDI_Host.kicad_pcb]
2023-03-28 SUKU resistor values updated
    [MIDI_Host.kicad_pcb, MIDI_Host.kicad_sch, power.kicad_sch]
2023-03-28 SUKU AB switch polarity fixed
    [uart_driver.c]
2023-04-07 Update README.md
    Better English and added missing information about the DC in port. See also https://github.com/intechstudio/knot/issues/5
2023-04-18 SUKU bootloader updated
    [MIDI_Host.kicad_pcb, MIDI_Host.kicad_sch, midi.kicad_sch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]
2023-04-18 SUKU updated layout done, cicd updated with position offset and v7 runner
    [MIDI_Host.kicad_pcb, MIDI_Host.kicad_sch, midi.kicad_sch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]
2023-04-18 SUKU DC jack grounding issue fixed
    [MIDI_Host.kicad_pcb, power.kicad_sch]
2023-04-24 SUKU oscilloscope ground connection added
    [MIDI_Host.kicad_pcb, MIDI_Host.kicad_sch]
2023-05-08 SUKU bootloader reverted
    [partitions-8MB.csv]
2023-05-09 SUKU bootloader binary updated
    [partitions-8MB.csv]
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2023-05-24 SUKU usb offset fixed, rotation descriptors added
    [MIDI_Host.kicad_pcb]
2023-05-24 SUKU usb footprint 3d model position updated
    [MIDI_Host.kicad_pcb]
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2023-07-27 SUKU dc jack value fixed
    [MIDI_Host.kicad_pcb, power.kicad_sch]
2023-10-31 SUKU descriptor maxlength updated, alternate settings handling implemented
    [MIDI_Host_assembly.FCStd]
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2024-01-08 SUKU organizing repository
    [MIDI_Host.kicad_pcb, MIDI_Host.kicad_sch, MIDI_Host_assembly-Alu.step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]
2024-01-08 SUKU folder renamed
    [partitions-8MB.csv]
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2024-01-26 SUKU uart error alert added
    [knot_midi_uart.c]
2024-03-13 SUKU trs midi rx hanging note fixed, latency introduced
    [knot_midi_uart.c, midi_host_fw.c]
2024-04-29 SUKU mechanical updated
    [MIDI_Host_assembly.FCStd, PCBA-KNOT.kicad_pcb]
2024-05-28 SUKU 3d files updated from library
    [PCBA-KNOT.kicad_pcb, PCBA-KNOT.kicad_sch]
2024-05-28 SUKU 3d files added
    [PCBA-KNOT.kicad_pcb, PCBA-KNOT.kicad_sch]
2024-05-29 SUKU ui library compatibility fixed, AB swich middle position defined using pullup
    [midi_host_fw.c]
2024-06-19 SUKU dc 3d updated
    [PCBA-KNOT.kicad_pcb]
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2024-06-25 KNOT_update done
    [KNOT-BACK.step, KNOT-FRONT.step, KNOT-HOUSING.step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]
2024-07-01 SUKU ki8 migration
    [PCBA-KNOT.kicad_pcb, PCBA-KNOT.kicad_sch, midi.kicad_sch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]
2024-07-01 SUKU erc fix
    [PCBA-KNOT.kicad_pcb]
2024-07-03 SUKU move
    [KNOT-BACK.step, KNOT-FRONT.step, KNOT-HOUSING.step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]
2024-07-03 SUKU file fixed
    [KNOT-ASSEMBLY.FCStd]
2024-07-09 KLD knot file explode
    [KNOT-ASSEMBLY.FCStd, KNOT-BACK.FCStd, KNOT-FRONT.FCStd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]
2024-07-10 KLD origin resets
    [KNOT-BACK.FCStd, KNOT-FRONT.FCStd]
2025-01-23 SUKU usb tx usb rx uart tx uart rx separated, retriggered idle hook implemented
2025-02-26 SUKU tht jack added
    [PCBA-KNOT.kicad_pcb, PCBA-KNOT.kicad_sch, midi.kicad_sch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]
2025-02-26 SUKU drc fixed
    [PCBA-KNOT.kicad_pcb]
2025-06-03 SUKU platform package added, build scripts fixed
    [midi_host_fw.c]
2025-09-10 Fix missing Running Status support for incoming MIDI on the UART
    Running Status is a standard feature of the classic MIDI protocol, which
    permits omitting the Status byte when sending a Voice or Mode message
    that has the same Status as the preceding message.
    Reference: MIDI 1.0 Detailed Specification, v4.2.1 (midi.org)
    Many devices make heavy use of this feature and don't work properly with
    the KNOT without this implemented. In my testing, this patch fixed MIDI
    reception from the following devices:
    - Yamaha CBX-K1XG "MIDI sound keyboard" (1995)
    - Yamaha QY70 portable sequencer (1997)
    - Yamaha PSR-350 arranger keyboard (2001)
    - Squier Stratocaster Guitar and Controller (2011)
    All were tes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
    [knot_midi_translator.c]
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2025-11-12 SUKU update nightly release to zip artifacts and rename release
    Changes:
    - Release name changed from "Release Nightly Version" to "Nightly Build"
    - Added zip step to package artifacts into knot_nightly.zip
    - Updated release to use zipped artifact instead of individual files
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2026-01-08 SUKU fix Real-Time Message handling during SysEx reception
    Real-Time Messages (0xF8-0xFF) must be processed immediately even when
    received during SysEx, per MIDI specification. Previously they were
    incorrectly stored in the SysEx buffer. Now they are returned immediately
    without affecting SysEx state or buffer.
    [knot_midi_translator.c]
2026-02-16 Use knot-specific lua UI init to avoid linking LCD draw functions
    grid_module.c references LCD draw symbols that knot doesn't need.
    Replace grid_lua_ui_init with a local knot_lua_ui_init that uses
    the new grid_common API but only handles the system element.
    [midi_host_fw.c]
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2026-02-25 Update electrical component links to use nightly-electrical release assets
    Replaces broken preview branch links with direct release download URLs.
    Drops unavailable pcb3d file, adds PCB Top/Bottom PDFs, BOM and
    Interactive BOM which are now available as release assets.
2026-02-25 Update mechanical component links to use nightly-mechanical release assets
    Adds engraving PDF for KNOT-HOUSING which is now available as a release asset.
    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
2026-02-26 Switch FreeCAD to AppImage and fix clean exit in mechanical CI
    - Replace conda-forge FreeCAD with FreeCAD 1.0.2 AppImage (faster build,
    more up-to-date than PPA)
    - Install pythonocc-core in a separate conda env (python=3.12) to avoid
    conflict with the base image's pinned Python 3.13
    - Use full path to occenv Python in Convert STEP to STL step
    - Replace App.Gui.getMainWindow().close() with sys.exit(0) so FreeCAD
    exits cleanly without hanging
    - Remove timeout hack from freecad invocation
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2026-02-26 Rename workflows to domain_workflow scheme and merge docker builds into main workflows
    - Rename firmware_workflow/mechanical_components/electrical_boards to *_workflow
    - Rename pre-commit to format_workflow
    - Rename reusable workflows with _ prefix convention
    - Remove standalone *_docker.yml files; merge conditional docker build-image job
    into each *_workflow.yml using dorny/paths-filter
    - Docker image builds only trigger on main/master branch Dockerfile changes
    - Board/firmware jobs wait for image build but run even when build-image is skipped
    - Remove top-level name: property from all workflow files
    - Move Dockerfiles to docker/ directory, move shell scripts to Firmware/
    - Add Firmware/d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
2026-02-26 Fix deploy-results being skipped due to needs chain skip propagation
    Add if: always() && needs.<job>.result == 'success' to all deploy/publish
    jobs to break the status propagation from skipped build-image through
    the always() generate-artifacts/build jobs.
2026-02-26 Unify nightly releases: add changelog to all, remove firmware-specific nightly workflow
    - Add mikepenz/release-changelog-builder-action to _deploy_nightly.yml
    so all three nightly releases (firmware, mechanical, electrical) get a changelog
    - Switch firmware publish-nightly to use _deploy_nightly.yml with
    tag_name nightly-firmware to match mechanical/electrical naming
    - Remove non-dated knot_esp32_nightly.uf2 duplicate from firmware build
    - Delete _firmware_release_nightly.yml (no longer needed)
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2026-02-26 Refactor CI: SHA-based Dockerfile detection and composite action
    Replace dorny/paths-filter Dockerfile change detection with Git SHA
    comparison using the org.opencontainers.image.revision OCI label stamped
    on each built image. Each build workflow now self-determines whether a
    rebuild is needed, removing the check-dockerfile job and dockerfile_changed
    input from all orchestrator and reusable workflows.
    Extract shared image prep logic (GHCR login + pull/compare/build/push)
    into a composite action at .github/actions/prepare-builder-image.
    Standardize all workflows on inline docker run --rm, dropping the
    background container pattern from mechanical and electrical. All three
    build workflows now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
